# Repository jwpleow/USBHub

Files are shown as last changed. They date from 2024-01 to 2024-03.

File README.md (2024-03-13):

## Impedance Control
Impedance control was done assuming manufacturing using JLCPCB 6 layer PCB JLC06161H-7628
90Ohms Diff Pair (usb) -> 0.127mm spacing, 0.16mm trace width
100Ohms Diff Pair (ethernet) -> 0.127mm spacing, 0.11mm trace width

## Min vias
We require 0.15mm/0.25mm vias ($$$$$$$$$$$$)

### Red LED for PD fault
KT-0603R
https://jlcpcb.com/partdetail/Hubei_KentoElec-KT0603R/C2286

## Power
### 5V
| Part Name | Description | Datasheet | JLCPCB |
| - | - | - | - |
| TPS56637RPAR | 4.5-V to 24-V In, 0.6-V to 7-V Out, 8-A Synchronous Step-Down Voltage Regulator | [Datasheet](https://www.ti.com/lit/ds/symlink/tps51396a.pdf) | [JLCPCB](https://jlcpcb.com/partdetail/TexasInstruments-TPS56637RPAR/C841386) | 
| FXL0630-3R3-M | Inductor 3.3uH (max 22mOhm) 8.5A | | [JLCPCB](https://jlcpcb.com/partdetail/178602-FXL0630_3R3M/C167219) |

### 3V3
| Part Name | Description | Datasheet | JLCPCB |
| - | - | - | - |
| TLV75733PDBVR |  Fixed 3.3V 1A SOT-23-5 25uA qI | | [JLCPCB](https://jlcpcb.com/partdetail/TexasInstruments-TLV75733PDBVR/C485517) |

### 1V2
| Part Name | Description | Datasheet | JLCPCB |
| - | - | - | - |
| TPS54331DR | Step-down type Adjustable 0.8V~25V 3A 3.5V~28V Buck converter | [Datasheet](https://www.ti.com/lit/ds/symlink/tps54331.pdf) | [JLCPCB](https://jlcpcb.com/partdetail/TexasInstruments-TPS54331DR/C9865) |
| FNR6045S180MT | Inductor 18uH ±20% 2.4A SMD,6x6mm, 81mOhm |  | [JLCPCB](https://jlcpcb.com/partdetail/179462-FNR6045S180MT/C168079) |

## USB
### Power Delivery

| Part Name | Description | Datasheet | JLCPCB |
| - | - | - | - |
| CYPD3177_24LQXQ | USB Type-C and Power Delivery (PD) Controller QFN-24 | [Datasheet](https://www.infineon.com/dgdl/Infineon-EZ-PD_BCR_Datasheet_USB_Type-C_Port_Controller_for_Power_Sinks-DataSheet-v03_00-EN.pdf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) | [JLCPCB](https://jlcpcb.com/partdetail/CypressSemicon-CYPD317724LQXQ/C2959321) | 
| BZT52C12 | Zener Diode | | [JLCPCB](https://jlcpcb.com/partdetail/Goodwork-BZT52C12/C2932744) | 
| SI3421DV-T1-GE3 | PMOSFET | | [JLCPCB](https://jlcpcb.com/partdetail/VishayIntertech-SI3421DV_T1GE3/C144884) | 
| SS54 | Schottky Diode for Reverse Polarity Protection | | [JLCPCB](https://jlcpcb.com/partdetail/Hongjiacheng-SS54/C7420369) |

### USB Data

| Part Name | Description | Datasheet | JLCPCB |
| - | - | - | - |
| CYUSB3304-68LTXCT | USB 3.2 Gen1 4-port Hub Controller | [Datasheet](https://www.infineon.com/dgdl/Infineon-CYUSB330x_CYUSB331x_CYUSB332x_HX3_USB_3.0_Hub-DataSheet-v21_00-EN.pdf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) | [JLCPCB](https://jlcpcb.com/partdetail/CypressSemicon-CYUSB330468LTXCT/C914921) |
| TUSB522PPRGER | 5Gbps USB3.0 redriver | [Datasheet](https://www.ti.com/lit/ds/symlink/tusb522p.pdf) | [JLCPCB](https://jlcpcb.com/parts/componentSearch?searchTxt=TUSB522P)  |
| PI3USB302-AZBEX | USB 3.0 Passive mux | [Datasheet](https://www.diodes.com/assets/Datasheets/PI3USB302-A.pdf) |  [JLCPCB](https://jlcpcb.com/partdetail/DiodesIncorporated-PI3USB302AZBEX/C500787) |
| TXM26M0004322CBCDO00T | Crystal for USB Hub Controller 26MHz +- 10ppm 9pF | | [JLCPCB](https://jlcpcb.com/partdetail/Yajingxin-TXM26M0004322CBCDO00T/C362346) |
<!-- | TUSB212IRWBR | USB 2.0 Signal Conditioner | [Datasheet](https://www.ti.com/lit/ds/symlink/tusb212.pdf) | [JLCPCB](https://jlcpcb.com/partdetail/TexasInstruments-TUSB212IRWBR/C2674396) | -->

### USB Ancillaries
| Part Name | Description | Datasheet | JLCPCB |
| - | - | - | - |
| GT-USB-7052 | USB Type-C Receptacle USB3.1 5A 24 Pins Vertical SMD | [Datasheet](https://www.dg-switch.com/uploads/soft/200510/GT-USB-7052.pdf) | [JLCPCB](https://jlcpcb.com/partdetail/gswitch-GT_USB7052/C963223) |
| PUSB3FR4Z | ESD Protection for differential pairs | [Datasheet](https://assets.nexperia.com/documents/data-sheet/PUSB3FR4.pdf) | [JLCPCB](https://jlcpcb.com/partdetail/Nexperia-PUSB3FR4Z/C503418)  |
| TI TVS2200DRVR | ESD Protection 28V for VBUS | [Datasheet](https://www.ti.com/lit/ds/symlink/tvs2200.pdf) | [JLCPCB](https://jlcpcb.com/partdetail/TexasInstruments-TVS2200DRVR/C523793) |
| TPS2069CDBVR | 1.5A Current limiting power distribution switch for USB DFP | [Datasheet](https://www.ti.com/lit/ds/symlink/tps2001c.pdf) | [JLCPCB](https://jlcpcb.com/partdetail/TexasInstruments-TPS2069CDBVR/C181752) |
| ESD5B5.0ST1G | 5.8V ESD Protection for DFP VBUS | [Datasheet](https://www.onsemi.com/pdf/datasheet/esd5b5.0st1-d.pdf) | [JLCPCB](https://jlcpcb.com/partdetail/Onsemi-ESD5B50ST1G/C93623) | 
| 484080003 | USB Type A Vertical | | [JLCPCB](https://jlcpcb.com/partdetail/Molex-484080003/C587839) |

### Ethernet USB 
| Part Name | Description | Datasheet | JLCPCB |
| - | - | - | - |
| RTL8153B-VB-CG | Ethernet-USB controller |  | [JLCPCB](https://jlcpcb.com/partdetail/RealtekSemicon-RTL8153B_VBCG/C2802072)  |
| G24P02S | RJ45 Transformer | | [JLCPCB](https://jlcpcb.com/partdetail/Jasn-G24P02S/C2827276)  |
| 7D025000Q01 | 25MHz Crystal, 18pF +- 10ppm | | [JLCPCB](https://jlcpcb.com/partdetail/Hd-7D025000Q01/C648942)|
| RC01931 | Ethernet Port Vertical | | [JLCPCB](https://jlcpcb.com/partdetail/Rch-RC01931/C708651) |

### Others
| Part Name | Description | Datasheet | JLCPCB |
| - | - | - | - |
| KT-0805G | LED Green | | [JLCPCB](https://jlcpcb.com/partdetail/Hubei_KentoElec-KT0805G/C2297) |
| BLM21PG221SN1D | Ferrite Bead 2A @ 85C | | [JLCPCB](https://jlcpcb.com/partdetail/MurataElectronics-BLM21PG221SN1D/C85840) |
| WJ103-5.0-2P | 2P 5mm screw terminal angled | | [JLCPCB](https://jlcpcb.com/partdetail/Ningbo_KangnexElec-WJ103_5_02P/C8439 )  |
| RVT1V151M0607 | 150u Aluminium Electrolytic Capacitor | | [JLCPCB](https://jlcpcb.com/partdetail/Roqang-RVT1V151M0607/C3032176) |
 <!-- | TI TPDxE05U06 | ESD Protection TVS 28V for CC / DP / DM?  | [Datasheet](https://www.ti.com/lit/ds/symlink/tpd4e05u06.pdf) | [JLCPCB](https://jlcpcb.com/partdetail/TexasInstruments-TPD4E05U06DQAR/C138714)  -->

## Buck Converter to 5V

## USB Hub Design Checklist
1 Are the decoupling capacitors and bulk capacitors connected as per Figure 1 and Figure 2? Y
2 Does the crystal meet the specification in this application note?  Y
3 Are all DS ports provided with 150-µF bulk capacitors? Y
4 Do the Power-on-Reset RC components meet the minimum reset time (5 ms)? Y
5 Do the USB precision resistors have 1% tolerance?  Y
6 Are the I2C lines provided with pull-up resistors to the 3.3-V domain? Y
7 Do the LEDs connected to the pin-strap pins have a 10-kΩ parallel resistor? Y
8
Is it ensured that the DS port power switch has a MOSFET connected to the OUTPUT pin or selected a power switch with
fast discharge? Y
9 Is the VBUS_US pin provided with a 10-kΩ voltage divider network? Y
10 Is the US port provided with 1-µF bulk capacitor? N
11 Are all port shields terminated properly?
12 Are the ferrite beads connected as shown in Figure 1 and Figure 2?
13
Are MODE_SEL[1] and MODE_SEL[0] not pulled LOW when the pin-strap configuration is used with HX3? (For 88-pin
QFN only).
14
Are values of the resistors connected in series to the LEDs decided based on the HX3’s I/O current source/sink capability
(4 mA)?
Layout Checklist
1 Is the crystal placed close to the chip (less than 1 cm)?
2 Are the decoupling capacitors and bulk capacitors placed close to the HX3 power pins?
3 Are the vias placed close to the HX3 power pins?
4 Are the power traces routed away from the high-speed data lines and the clock lines?
5 Is the capacitor in the RC reset circuitry placed close to the reset pin of HX3?
6 Is the 150-µF capacitor placed close to the DS port connector?
7 Are the USB SS and HS signal lines matched in length?
8 Are the USB data lines provided with solid ground plane underneath?
9 Are the SS traces provided with the guard traces along the USB data trace with stitching vias?
10 Are the SS traces provided with the AC decoupling capacitors (0.1 µF) on the TX lines?
11 Are the USB traces kept as short as possible?
12 Is it ensured that there are no stubs on all the USB traces?
13 Is it ensured that there are no vias on the SS traces?
14 Do the USB traces have few bends and no 90-degree bends?

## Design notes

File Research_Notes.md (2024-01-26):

# Notes
https://www.youtube.com/watch?v=W13HNsoHj7A USB-C Power Delivery Hardware Design - Phil's Lab #104
https://www.ti.com/lit/wp/slyy109b/slyy109b.pdf?ts=1704425741746 A Primer on USB Type-C and USBPower Delivery Applications and Requirements

# USB 3 hub examples
https://github.com/DynamixYANG/highendusb3hub
https://www.ti.com/lit/ug/slla312c/slla312c.pdf

# USB PD examples
https://www.ti.com/lit/ug/slvubo9a/slvubo9a.pdf

# Parts check: 
https://www.pcbway.com/components/
https://jlcpcb.com/parts/

## Find Symbols + Footprints
https://componentsearchengine.com/
https://easyeda.com/

# STM32
STM32F103C8T6 https://jlcpcb.com/partdetail/Stmicroelectronics-STM32F103C8T6/C8734

QFN package - more complicated :0?
3.3V <- Needs a regulator from USB, ~100mA?
USB natively on board!
CAN timers 

# DC converter
harder to route than an LDO regulator

How to choose switching regulator:
SMD type 
Skip BGA (expensive to assemble)

Pick simple `Buck` in Topology..
Pick correct output voltage & output current

### Recommendations by https://www.youtube.com/watch?v=_4h2ZD8O9Ms
1. TUSB422 + TPS65987D + TUSB542 + TUSB212 (5Gbps)
2. TUSB422 + TPS65987D + TUSB1042I + TUSB212 (10Gbps)

TPS65987D -> Power delivery
TUSB212 -> USB 2 controller

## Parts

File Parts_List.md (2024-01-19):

# Power

### Power delivery controller - CYPD3177-24LQXQ
https://au.mouser.com/datasheet/2/196/CYPR_S_A0012903526_1-3004964.pdf
https://jlcpcb.com/partdetail/CypressSemicon-CYPD317724LQXQ/C2959321

### MOSFET for PD controller 
#### SI3421DV-T1-GE3
https://jlcpcb.com/partdetail/VishayIntertech-SI3421DV_T1GE3/C144884

### Zener Diode for PD controller
https://jlcpcb.com/partdetail/Goodwork-BZT52C12/C2932744

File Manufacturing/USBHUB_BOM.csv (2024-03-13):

Designator | Qnty | Comment | Cmp name | Footprint | Description | JLCPCB Part #
C1, C115, C119, C123 | 4 | 150u | C_Small | Capacitor_SMD:C_Elec_6.3x7.7 | Unpolarized capacitor, small symbol | C3032176
C2, C3, C5, C7, C18, C19, C53, C57, C73, C87, C100, C106, C130, C132 | 14 | 1u | C_Small | 0603 | Unpolarized capacitor, small symbol | C15849
C4 | 1 | 3u3 | C_Small | 0603 | Unpolarized capacitor, small symbol | C5360803
C6, C8, C9, C20, C22, C114, C116, C117, C118, C120, C121, C122, C124, C125 | 14 | 100n | C_Small | 0603 | Unpolarized capacitor, small symbol | C30926
C10, C11, C52, C72, C86, C99, C105, C113 | 8 | 22u | C | 0603 | Unpolarized capacitor | C59461
C12, C13, C131, C133, C134 | 5 | 4u7 | C_Small | 0603 | Unpolarized capacitor, small symbol | C19666
C14, C16 | 2 | 10n | C_Small | 0603 | Unpolarized capacitor, small symbol | C57112
C15 | 1 | 3n9 | C_Small | 0603 | Unpolarized capacitor, small symbol | C2169349
C17 | 1 | 18n | C_Small | 0603 | Unpolarized capacitor, small symbol | C519551
C21, C23, C24 | 3 | 22u | C | 0805 | Unpolarized capacitor | C45783
C25 | 1 | 100p | C | 0603 | Unpolarized capacitor | C14858
C26, C27, C28, C29, C58, C60, C62, C64, C66, C68, C75, C77, C79, C81, C89, C91, C93, C95, C97, C102, C104, C108, C110, C112, C147, C148, C149, C151, C152 | 29 | 10n | C_Small | 0402 | Unpolarized capacitor, small symbol | C15195
C30, C31 | 2 | 220pF | C_Small | 0402 | Unpolarized capacitor, small symbol | C1530
C32, C35, C38, C39, C40, C128 | 6 | 10u | C_Small | 0603 | Unpolarized capacitor, small symbol | C19702
C33, C34, C36, C37, C41, C42, C43, C44, C45, C46, C47, C48, C49, C54, C55, C56, C59, C70, C71, C74, C76, C78, C80, C82, C83, C84, C85, C88, C101, C103, C107, C109, C111, C129, C135, C136, C137, C138, C139, C140, C141, C142, C143, C144, C145, C146, C153 | 47 | 100n | C_Small | 0402 | Unpolari capacitor, small symbol | C1525
C50, C51 | 2 | 10p | C | 0402 | Unpolarized capacitor | C32949
C61, C63, C65, C67, C69, C90, C92, C94, C96, C98 | 10 | 1n | C_Small | 0402 | Unpolarized capacitor, small symbol | C1523
C126, C127 | 2 | 27p | C | 0402 | Unpolarized capacitor | C1557
C150 | 1 | 1n/2KV | C | 1206 | Unpolarized capacitor | C9196
D1 | 1 | BZT52C12 | D_Zener | Diode_SMD:D_SOD-123 | Zener diode | C2932744
D2, D14 | 2 | RED | LED | 0603 | Light emitting diode | C2286
D3, D18 | 1 | SS54 | D_Schottky | Diode_SMD:D_SMA | 40V 5A Schottky Barrier Rectifier Diode, SMA | C7420369
D4 | 1 | GREEN | LED | 0603 | Light emitting diode | C2297
D5, D6, D7, D8, D9, D10, D11, D12, D13 | 9 | PUSB3FR4Z | PUSB3FR4Z | PUSB3FR4Z |  | C503418
D15, D16, D17 | 3 | ESD5B5.0ST1G | D_Zener | Diode_SMD:D_SOD-523 | Zener diode | C93623
FB1, FB2 | 2 | BLM21PG221SN1D | FerriteBead_Small | 0805 | Ferrite bead, small symbol | C85840
J1 | 1 | USB_C_Receptacle | USB_C_Receptacle | USB_C_Receptacle_GT-USB-7028x |  | C963223
J2 | 1 | RC01931 | RC01931 | RC01931 | Ethernet RJ45, Vertical | C708651
J3 | 1 | Screw_Terminal_01x02 | Screw_Terminal_01x02 | TerminalBlock_WJ103-5.0-2P | Generic screw terminal, single row, 01x02, script genera (kicad-library-utils/schlib/autogen/connector/) | C8439
L1 | 1 | 18u | L | FNR6045Sx | Inductor | C168079
L2 | 1 | 3.3u | L | FXL0630x | Inductor | C167219
Q1, Q2 | 2 | SI3421DV | SI3421DV | Package_TO_SOT_SMD:SOT-23-6 | P-MOSFET transistor, gate/source/drain | C144884
R1 | 1 | 10k | R | 0603 | Resistor | C25804
R2 | 1 | 50k | R | 0603 | Resistor | C304067
R3, R5, R6, R7, R13, R15, R16, R18, R19, R21, R30, R31, R32, R33, R34, R38, R39, R40, R41, R43 | 20 | 10k | R_Small | 0402 | Resistor | C25744
R4, R24, R25, R26, R27, R48, R49 | 7 | 1k | R | 0603 | Resistor | C25744
R8, R9, R35, R36 | 4 | 2k | R | 0402 | Resistor | C4109
R10, R11, R12, R22, R23, R37 | 6 | 5k1 | R | 0603 | Resistor | C23186
R14 | 1 | 953 | R | 0603 | Resistor | C311896
R17 | 1 | 100k | R | 0603 | Resistor | C25803
R20 | 1 | 73k2 | R | 0402 | Resistor | C185398
R28 | 1 | 200_1% | R | 0402 | Resistor | C25087
R29 | 1 | 6k04_1% | R | 0402 | Resistor | C25913
R42 | 1 | 2k49_1% | R_Small | 0603 | Resistor | C22908
R44, R45, R46, R47 | 4 | 75 | R_Small | 0603 | Resistor | C4275
R50, R51 | 2 | 10k | R_Small | 0402 | Resistor | C25744
T1 | 1 | G24P02S | G24P02S | G24P02S | RJ45 100/1000 Base-T SMT Transformer | C2827276
U1 | 1 | CYPD3177_24x | CYPD3177_24x | CYPD3177_24LQx_QFN-24_EP_4x4_Pitch0.5mm | USB Type-C PD Port Controller for Power Sinks | C2959321
U2 | 1 | TPS54331 | TPS54331DR | TPS54331DR | 3.5 to 28-V Input, 3A Step Down Buck Converter 570kHz | C9865
U3 | 1 | TLV75733PDBV | TLV75733PDBV | Package_TO_SOT_SMD:SOT-23-5 | 1A Low IQ Small Size Low Dropout Voltage Regulator, Fixed Output 3. SOT-23-5 | C485517
U4 | 1 | TPS56637RPAR | TPS56637RPAR | TPS56637RPAR |  | C841386
U5 | 1 | TVS2200DRVx | TVS2200DRVx | TVS2200DRVx |  | C523793
U6 | 1 | PI3USB302-Ax | PI3USB302-Ax | PI3USB302-Ax | 3.3V, USB 3.0, 1-Port, 2:1 Mux/DeMux Switch | C500787
U7 | 1 | TUSB522Px | TUSB522Px | TUSB522Px | 3.3 V Dual-Channel USB 3.1 GEN 1 Redriver, Equalizer | C2675181
U8, U9, U10 | 3 | USB_3_Type_A_Molex_484080003 | USB_3_Type_A_Molex_484080003 | Molex_484080003 |  | C587839
U11 | 1 | CYUSB3304-68LTXx | CYUSB3304-68LTXx | CYUSB3304-68LTXx |  | C914921
U12, U13, U14 | 3 | TPS20xxC | TPS20xxC | Package_TO_SOT_SMD:SOT-23-5 |  | C181752
U15 | 1 | RTL8153-VB-CG | RTL8153B-VB-CG | RTL8153B-VB-CG |  | C2802072
Y1 | 1 | 26MHz | Crystal_GND24 | Crystal:Crystal_SMD_3225-4Pin_3.2x2.5mm | Four pin crystal, GND on pins 2 and 4 | C362346
Y2 | 1 | 25MHz 18pF | Crystal_GND24 | Crystal:Crystal_SMD_2016-4Pin_2.0x1.6mm | Four pin crystal, GND on pins 2 and 4 | C648942

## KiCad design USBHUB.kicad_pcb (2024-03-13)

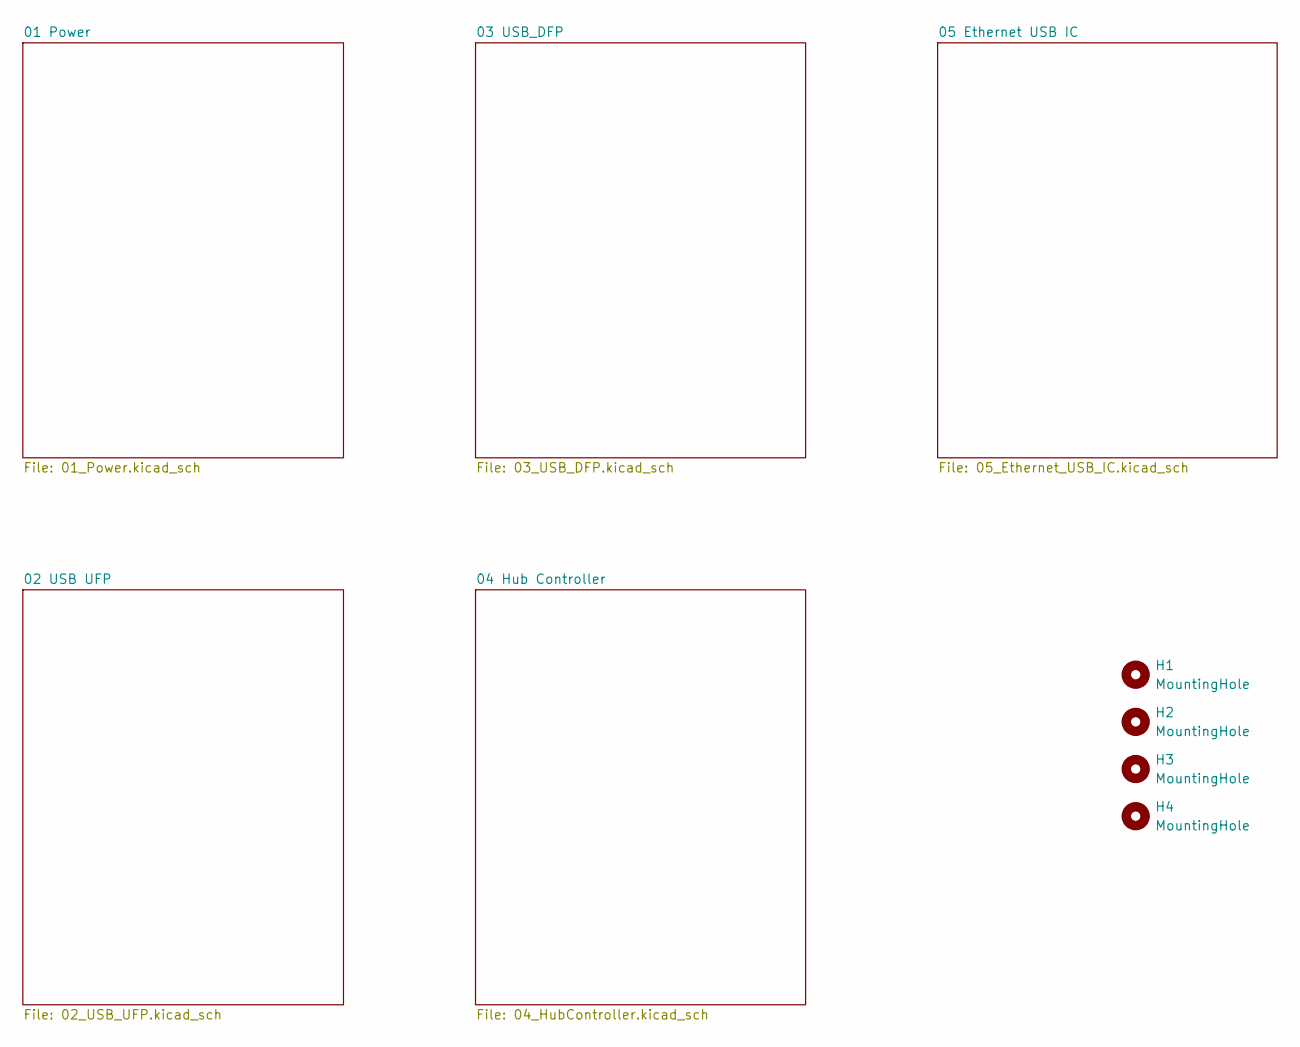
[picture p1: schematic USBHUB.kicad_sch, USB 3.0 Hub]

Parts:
H1, H2, H3, H4: MountingHole; MountingHole_2.7mm_M2.5

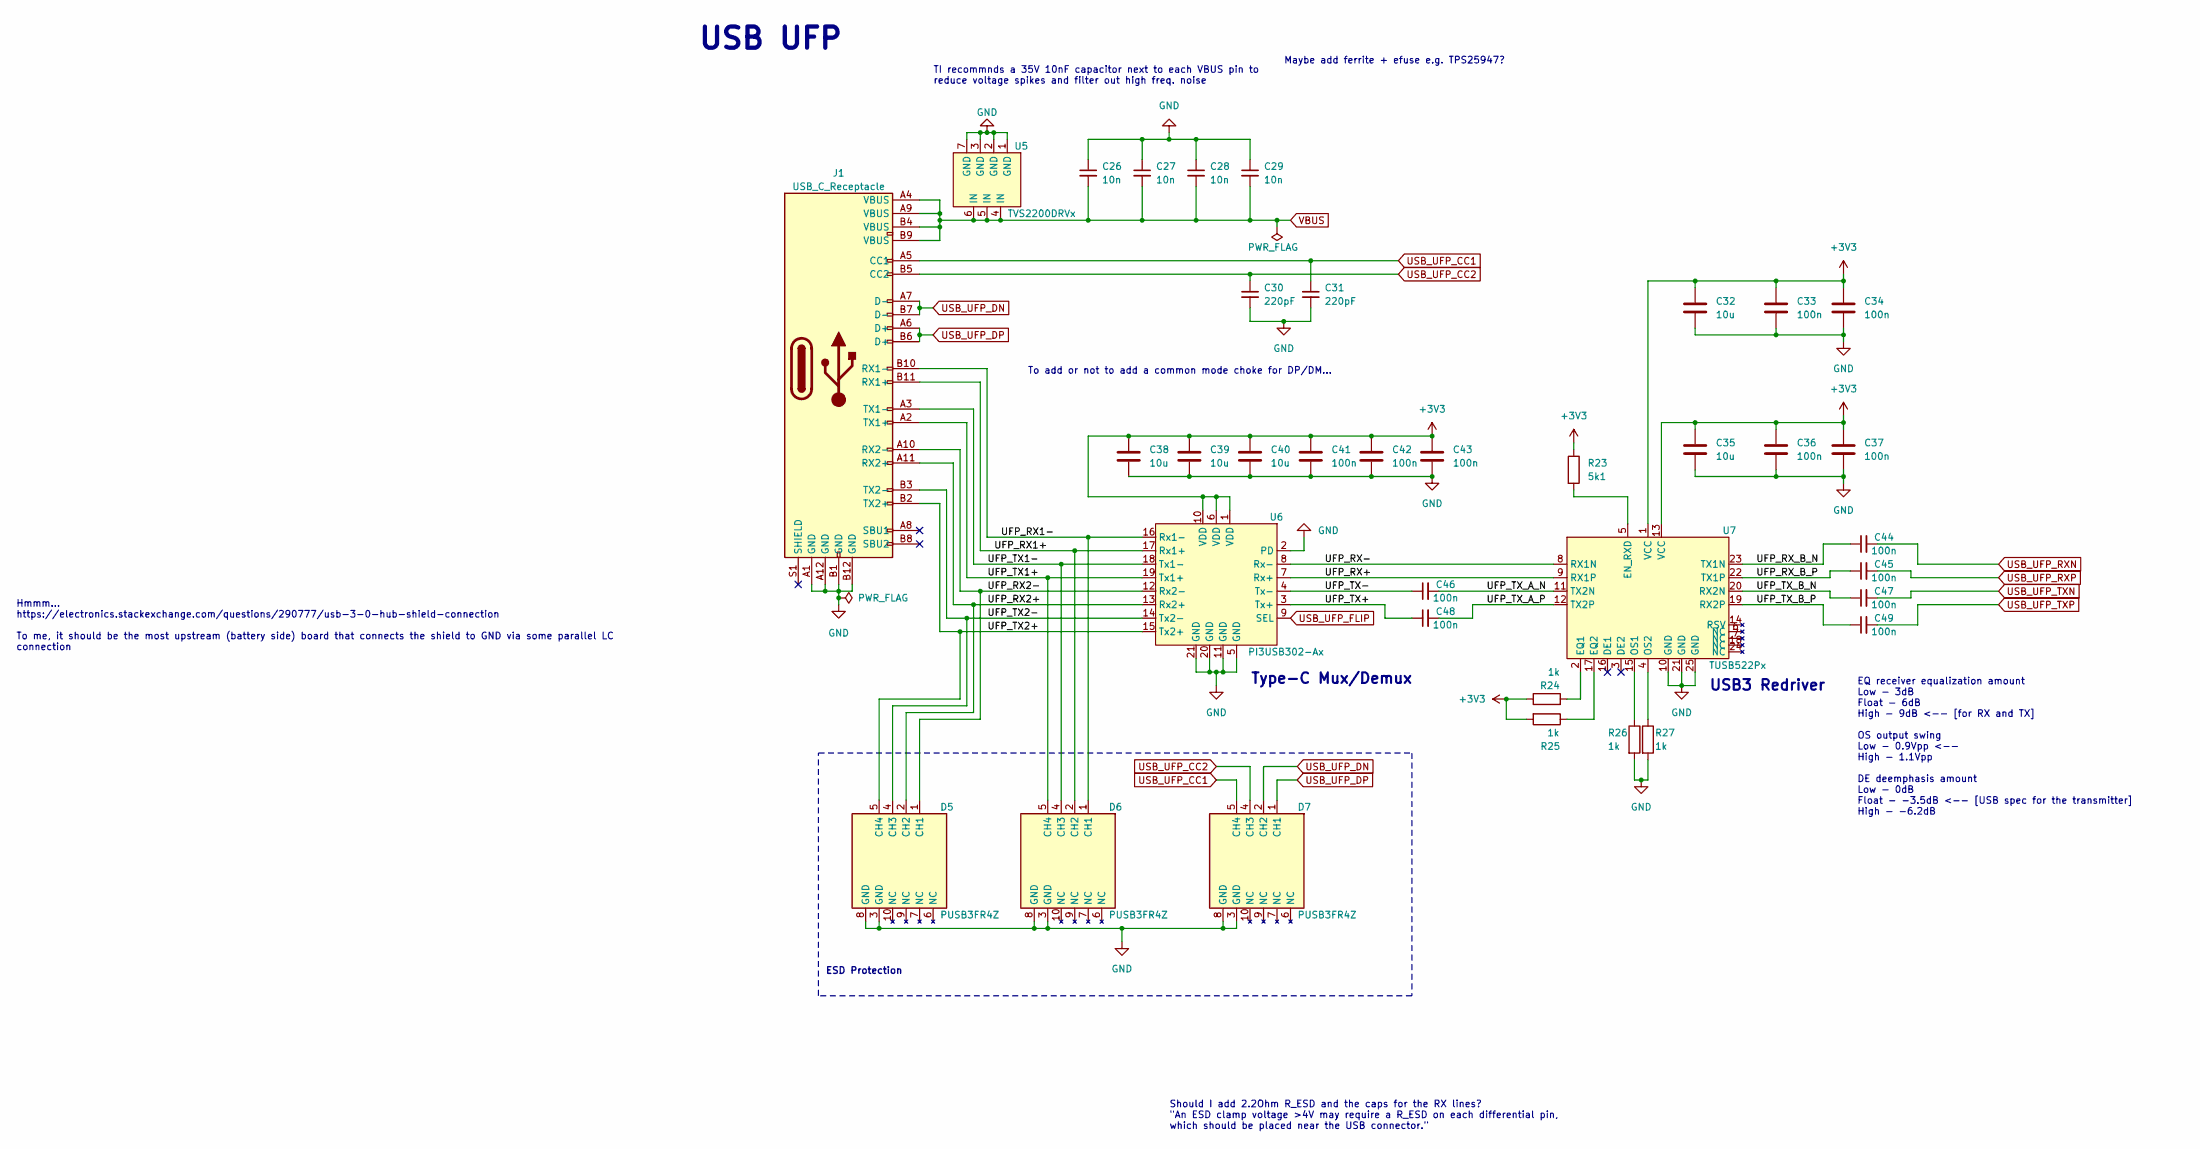
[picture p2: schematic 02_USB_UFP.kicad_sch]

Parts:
C26, C27, C28, C29: 10n; C_0402_1005Metric
C30, C31: 220pF; C_0402_1005Metric
C32, C35, C38, C39, C40: 10u; C_0603_1608Metric
C33, C34, C36, C37, C41, C42, C43, C44, C45, C46, C47, C48, C49: 100n; C_0402_1005Metric
D5, D6, D7: PUSB3FR4Z
J1: USB_C_Receptacle; USB_C_Receptacle_GT-USB-7028x
R23: 5k1; R_0603_1608Metric
R24, R25, R26, R27: 1k; R_0603_1608Metric
U5: TVS2200DRVx
U6: PI3USB302-Ax
U7: TUSB522Px

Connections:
+3V3: C32.1, C33.1, C34.1, C35.1, C36.1, C37.1, C38.1, C39.1, C40.1, C41.1, C42.1, C43.1, R23.1, R24.1, R25.2, U6.1 (VDD), U6.6 (VDD), U6.10 (VDD), U7.1 (VCC), U7.13 (VCC); also elsewhere on the board
/02 USB UFP/UFP_RX1+: D6.2 (CH2), J1.B11 (RX1+), U6.17 (Rx1+)
/02 USB UFP/UFP_RX1-: D6.1 (CH1), J1.B10 (RX1-), U6.16 (Rx1-)
/02 USB UFP/UFP_RX2+: D5.2 (CH2), J1.A11 (RX2+), U6.13 (Rx2+)
/02 USB UFP/UFP_RX2-: D5.1 (CH1), J1.A10 (RX2-), U6.12 (Rx2-)
/02 USB UFP/UFP_RX+: U6.7 (Rx+), U7.9 (RX1P)
/02 USB UFP/UFP_RX-: U6.8 (Rx-), U7.8 (RX1N)
/02 USB UFP/UFP_RX_B_N: C44.1, U7.23 (TX1N)
/02 USB UFP/UFP_RX_B_P: C45.1, U7.22 (TX1P)
/02 USB UFP/UFP_TX1+: D6.5 (CH4), J1.A2 (TX1+), U6.19 (Tx1+)
/02 USB UFP/UFP_TX1-: D6.4 (CH3), J1.A3 (TX1-), U6.18 (Tx1-)
/02 USB UFP/UFP_TX2+: D5.5 (CH4), J1.B2 (TX2+), U6.15 (Tx2+)
/02 USB UFP/UFP_TX2-: D5.4 (CH3), J1.B3 (TX2-), U6.14 (Tx2-)
/02 USB UFP/UFP_TX+: C48.1, U6.3 (Tx+)
/02 USB UFP/UFP_TX-: C46.1, U6.4 (Tx-)
/02 USB UFP/UFP_TX_A_N: C46.2, U7.11 (TX2N)
/02 USB UFP/UFP_TX_A_P: C48.2, U7.12 (TX2P)
/02 USB UFP/UFP_TX_B_N: C47.1, U7.20 (RX2N)
/02 USB UFP/UFP_TX_B_P: C49.1, U7.19 (RX2P)
GND: C26.1, C27.1, C28.1, C29.1, C30.2, C31.2, C32.2, C33.2, C34.2, C35.2, C36.2, C37.2, C38.2, C39.2, C40.2, C41.2, C42.2, C43.2, D5.3 (GND), D5.8 (GND), D6.3 (GND), D6.8 (GND), D7.3 (GND), D7.8 (GND), J1.A1 (GND), J1.A12 (GND), J1.B1 (GND), J1.B12 (GND), R26.2, R27.2, U5.1 (GND), U5.2 (GND), U5.3 (GND), U5.7 (GND), U6.2 (PD), U6.5 (GND), U6.11 (GND), U6.20 (GND), U6.21 (GND), U7.10 (GND), U7.21 (GND), U7.25 (GND); also elsewhere on the board
unnamed: R23.2, U7.5 (EN_RXD)
unnamed: R24.2, U7.2 (EQ1)
unnamed: R25.1, U7.17 (EQ2)
unnamed: R26.1, U7.15 (OS1)
unnamed: R27.1, U7.4 (OS2)
USB_UFP_CC1: C31.1, D7.5 (CH4), J1.A5 (CC1); also elsewhere on the board
USB_UFP_CC2: C30.1, D7.4 (CH3), J1.B5 (CC2); also elsewhere on the board
USB_UFP_DN: D7.2 (CH2), J1.A7 (D-), J1.B7 (D-); also elsewhere on the board
USB_UFP_DP: D7.1 (CH1), J1.A6 (D+), J1.B6 (D+); also elsewhere on the board
USB_UFP_FLIP: U6.9 (SEL); also elsewhere on the board
USB_UFP_RXN: C44.2; also elsewhere on the board
USB_UFP_RXP: C45.2; also elsewhere on the board
USB_UFP_TXN: C47.2; also elsewhere on the board
USB_UFP_TXP: C49.2; also elsewhere on the board
VBUS: C26.2, C27.2, C28.2, C29.2, J1.A4 (VBUS), J1.A9 (VBUS), J1.B4 (VBUS), J1.B9 (VBUS), U5.4 (IN), U5.5 (IN), U5.6 (IN); also elsewhere on the board

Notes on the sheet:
TI recommnds a 35V 10nF capacitor next to each VBUS pin to reduce voltage spikes and filter out high freq. noise
Maybe add ferrite + efuse e.g. TPS25947?
Type-C Mux/Demux
ESD Protection
To add or not to add a common mode choke for DP/DM...
EQ receiver equalization amount Low - 3dB Float - 6dB High - 9dB <-- [for RX and TX] OS output swing Low - 0.9Vpp <-- High - 1.1Vpp DE deemphasis amount Low - 0dB Float - -3.5dB <-- [USB spec for the transmitter] High - -6.2dB
USB3 Redriver
Hmmm... https://electronics.stackexchange.com/questions/290777/usb-3-0-hub-shield-connection To me, it should be the most upstream (battery side) board that connects the shield to GND via some parallel LC connection
Should I add 2.2Ohm R_ESD and the caps for the RX lines? "An ESD clamp voltage >4V may require a R_ESD on each differential pin, which should be placed near the USB connector."
USB UFP

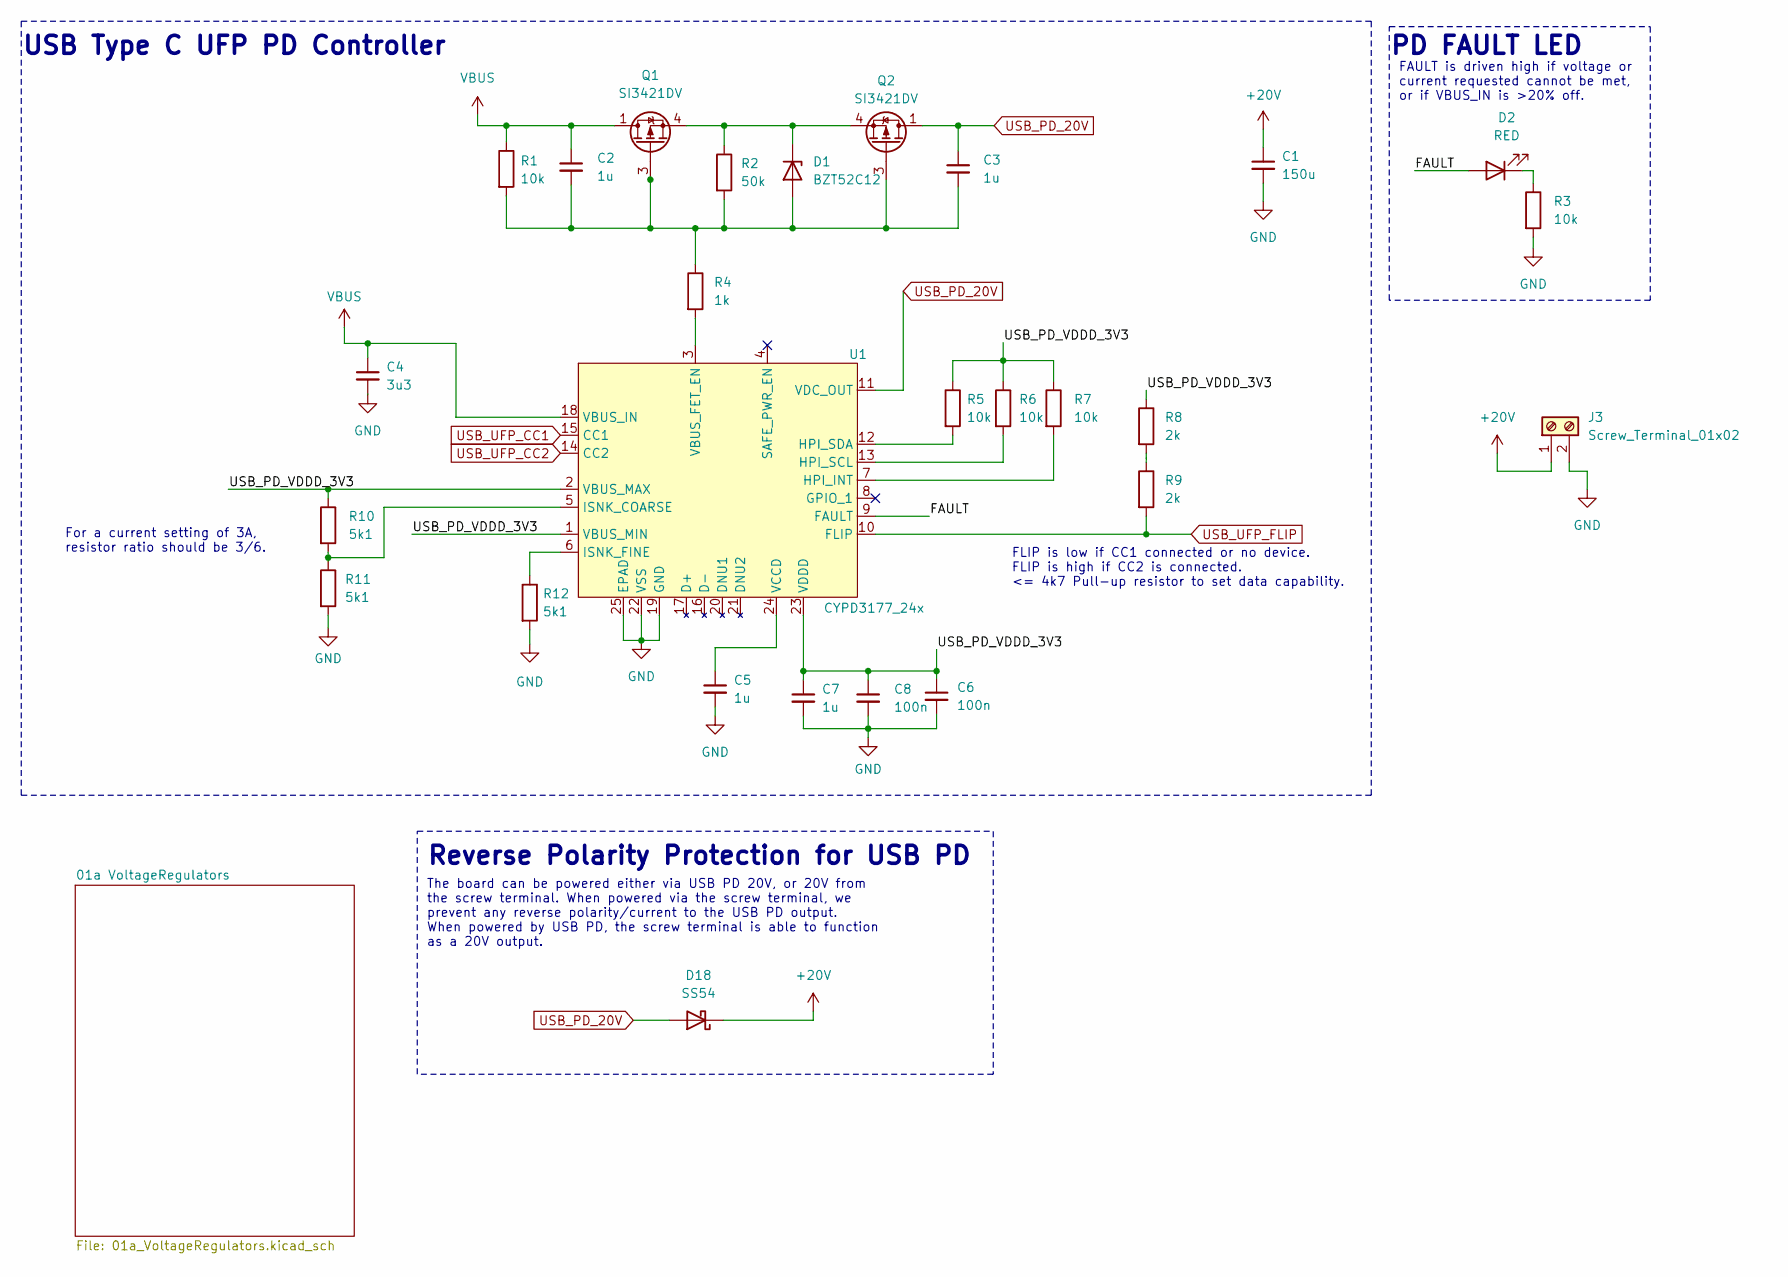
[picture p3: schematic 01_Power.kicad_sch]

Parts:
C1: 150u; C_Elec_6.3x7.7
C2, C3, C5, C7: 1u; C_0603_1608Metric
C4: 3u3; C_0603_1608Metric
C6, C8: 100n; C_0603_1608Metric
D1: BZT52C12; D_SOD-123
D2: RED; LED_0603_1608Metric
D18: SS54; D_SMA
J3: Screw_Terminal_01x02; TerminalBlock_WJ103-5.0-2P
Q1, Q2: SI3421DV; SOT-23-6
R1: 10k; R_0603_1608Metric
R2: 50k; R_0603_1608Metric
R3, R5, R6, R7: 10k; R_0402_1005Metric
R4: 1k; R_0603_1608Metric
R8, R9: 2k; R_0402_1005Metric
R10, R11, R12: 5k1; R_0603_1608Metric
U1: CYPD3177_24x; CYPD3177_24LQx_QFN-24_EP_4x4_Pitch0.5mm

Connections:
+20V: C1.1, D18.1 (K), J3.1; also elsewhere on the board
/01 Power/FAULT: D2.2 (A), U1.9 (FAULT)
/01 Power/USB_PD_VDDD_3V3: C6.1, C7.1, C8.1, R5.1, R6.1, R7.1, R8.1, R10.1, U1.1 (VBUS_MIN), U1.2 (VBUS_MAX), U1.23 (VDDD)
GND: C1.2, C4.2, C5.2, C6.2, C7.2, C8.2, J3.2, R3.2, R11.2, R12.2, U1.19 (GND), U1.22 (VSS), U1.25 (EPAD); also elsewhere on the board
unnamed: C2.2, C3.2, D1.2 (A), Q1.3 (G), Q2.3 (G), R1.2, R2.2, R4.1
unnamed: D1.1 (K), Q1.4 (S), Q2.4 (S), R2.1
unnamed: D2.1 (K), R3.1
unnamed: R8.2, R9.1
unnamed: R7.2, U1.7 (HPI_INT)
unnamed: R6.2, U1.13 (HPI_SCL)
unnamed: R5.2, U1.12 (HPI_SDA)
unnamed: R10.2, R11.1, U1.5 (ISNK_COARSE)
unnamed: R12.1, U1.6 (ISNK_FINE)
unnamed: R4.2, U1.3 (VBUS_FET_EN)
unnamed: C5.1, U1.24 (VCCD)
USB_PD_20V: C3.1, D18.2 (A), Q2.1 (D), Q2.2 (D1), Q2.5 (D2), Q2.6 (D3), U1.11 (VDC_OUT)
USB_UFP_CC1: U1.15 (CC1); also elsewhere on the board
USB_UFP_CC2: U1.14 (CC2); also elsewhere on the board
USB_UFP_FLIP: R9.2, U1.10 (FLIP); also elsewhere on the board
VBUS: C2.1, C4.1, Q1.1 (D), Q1.2 (D1), Q1.5 (D2), Q1.6 (D3), R1.1, U1.18 (VBUS_IN); also elsewhere on the board

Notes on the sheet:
For a current setting of 3A, resistor ratio should be 3/6.
FLIP is low if CC1 connected or no device. FLIP is high if CC2 is connected. <= 4k7 Pull-up resistor to set data capability.
USB Type C UFP PD Controller
PD FAULT LED
The board can be powered either via USB PD 20V, or 20V from the screw terminal. When powered via the screw terminal, we prevent any reverse polarity/current to the USB PD output. When powered by USB PD, the screw terminal is able to function as a 20V output.
Reverse Polarity Protection for USB PD
FAULT is driven high if voltage or current requested cannot be met, or if VBUS_IN is >20% off.

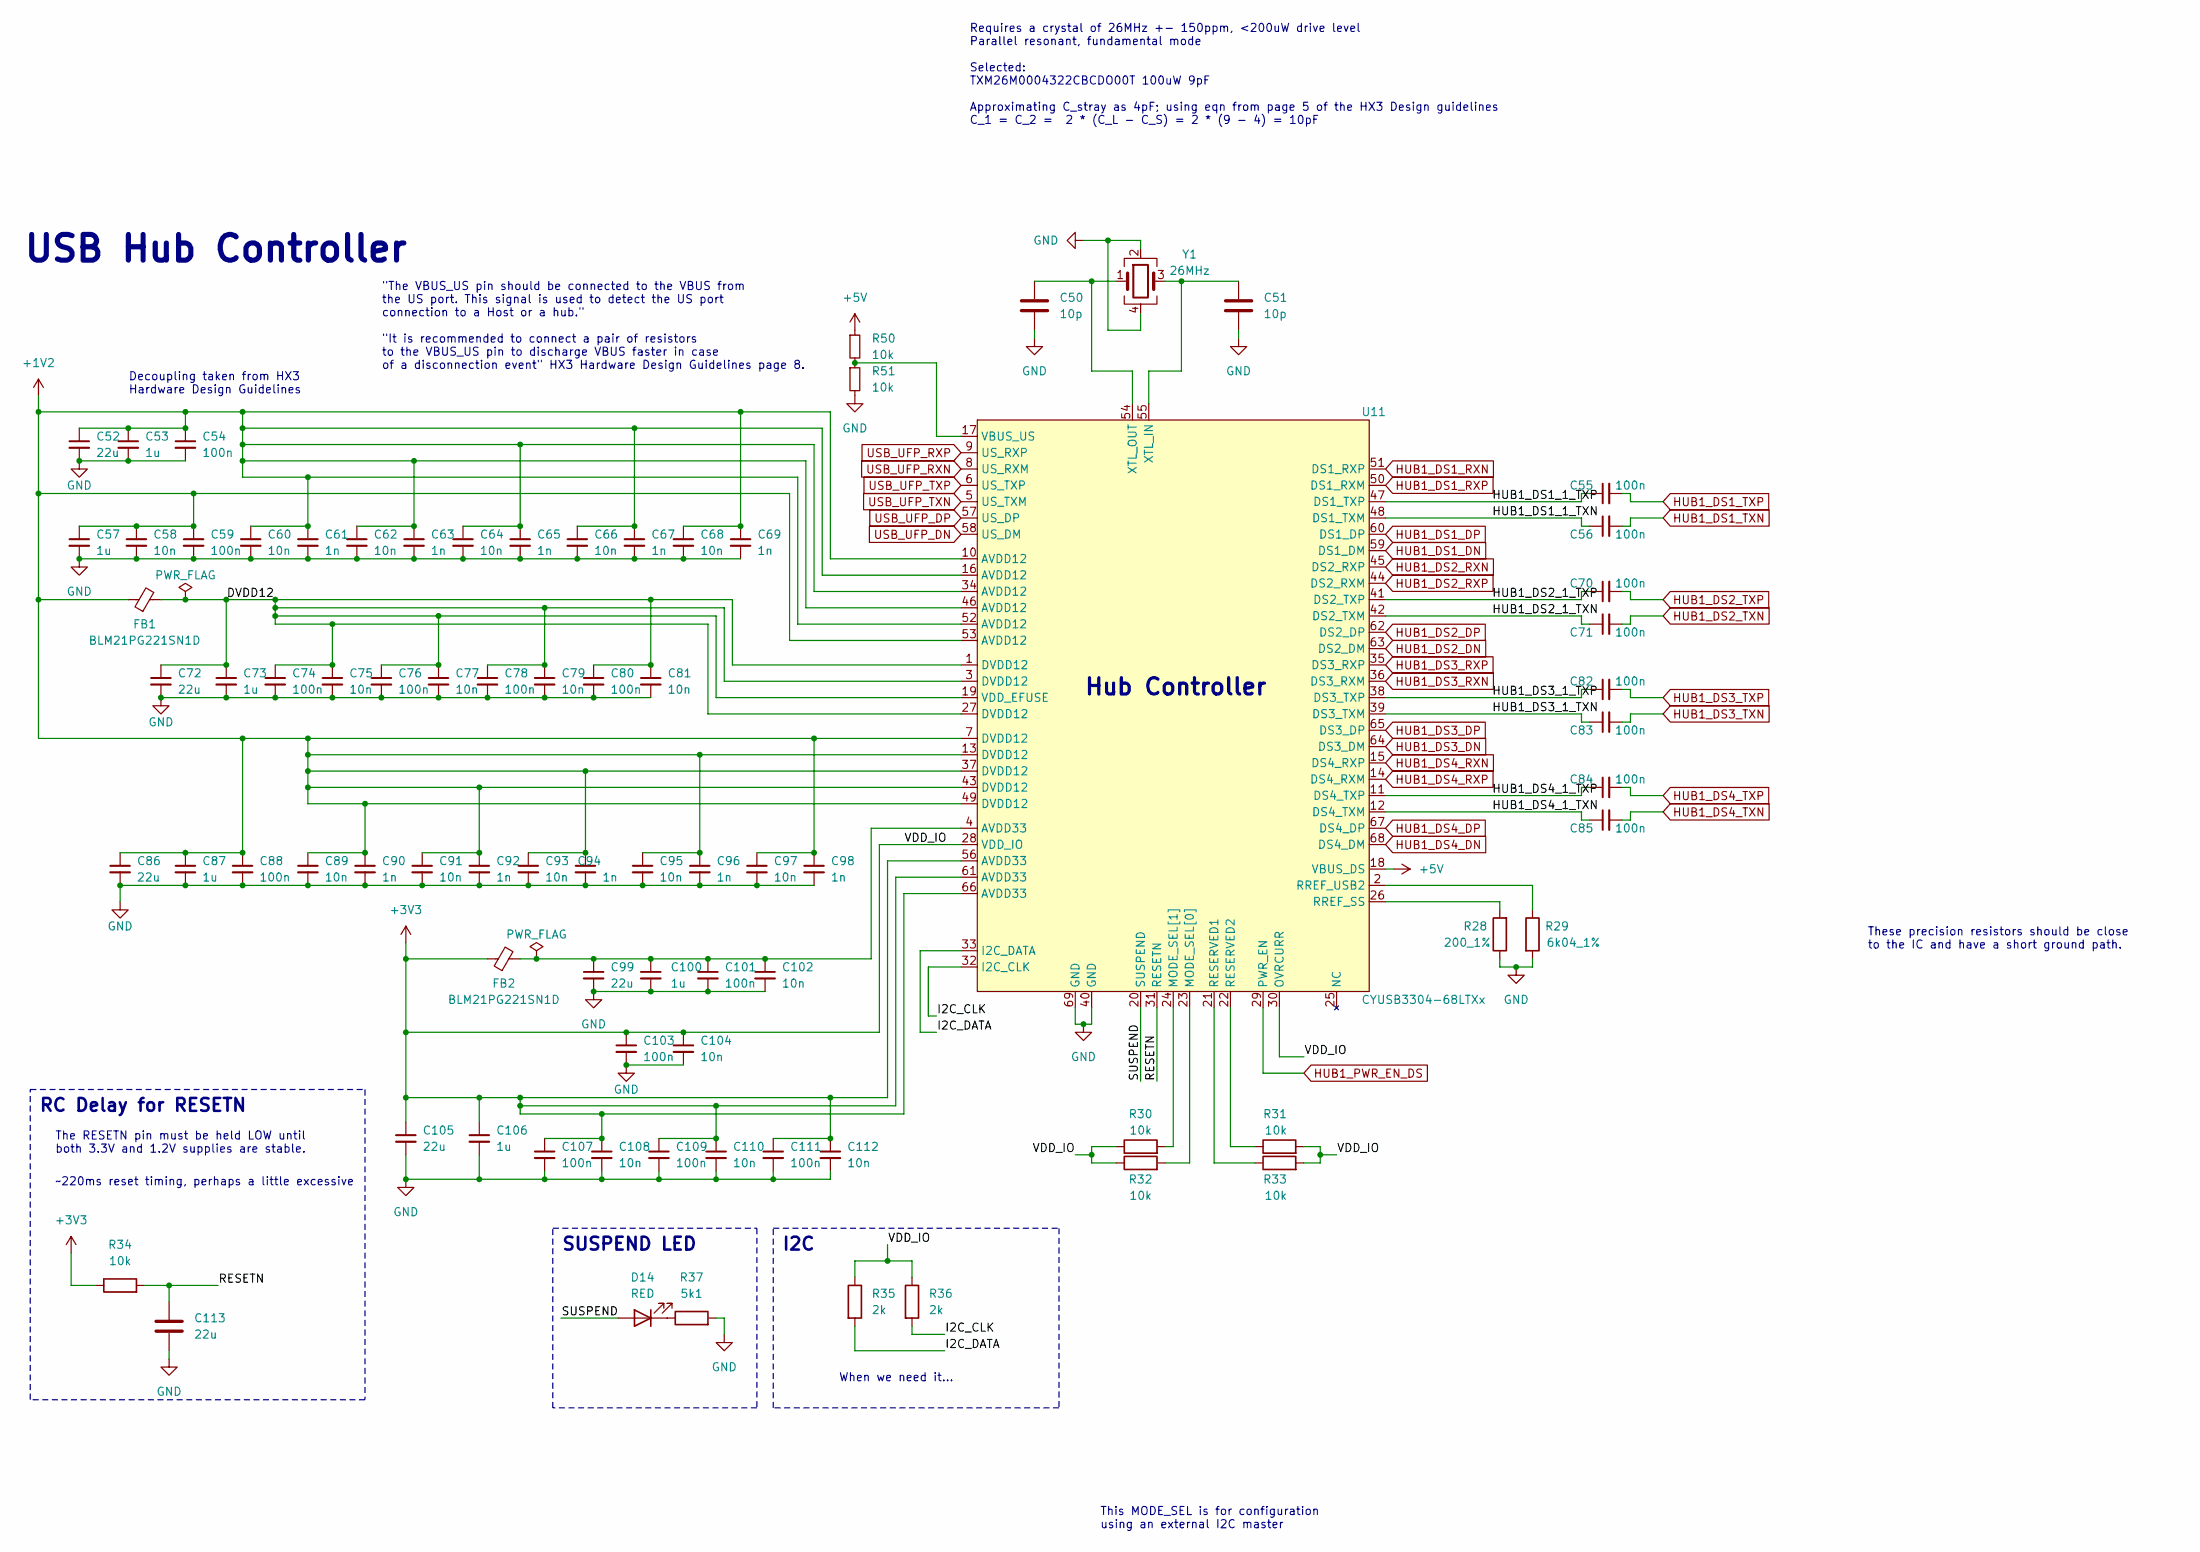
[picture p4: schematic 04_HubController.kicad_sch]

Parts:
C50, C51: 10p; C_0402_1005Metric
C52, C72, C86, C99, C105, C113: 22u; C_0603_1608Metric
C53, C57, C73, C87, C100, C106: 1u; C_0603_1608Metric
C54, C55, C56, C59, C70, C71, C74, C76, C78, C80, C82, C83, C84, C85, C88, C101, C103, C107, C109, C111: 100n; C_0402_1005Metric
C58, C60, C62, C64, C66, C68, C75, C77, C79, C81, C89, C91, C93, C95, C97, C102, C104, C108, C110, C112: 10n; C_0402_1005Metric
C61, C63, C65, C67, C69, C90, C92, C94, C96, C98: 1n; C_0402_1005Metric
D14: RED; LED_0603_1608Metric
FB1, FB2: BLM21PG221SN1D; L_0805_2012Metric
R28: 200_1%; R_0402_1005Metric
R29: 6k04_1%; R_0402_1005Metric
R30, R31, R32, R33, R34, R50, R51: 10k; R_0402_1005Metric
R35, R36: 2k; R_0402_1005Metric
R37: 5k1; R_0603_1608Metric
U11: CYUSB3304-68LTXx
Y1: 26MHz; Crystal_SMD_3225-4Pin_3.2x2.5mm

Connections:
+1V2: C52.1, C53.1, C54.1, C57.1, C58.1, C59.1, C60.1, C61.1, C62.1, C63.1, C64.1, C65.1, C66.1, C67.1, C68.1, C69.1, C86.1, C87.1, C88.1, C89.1, C90.1, C91.1, C92.1, C93.1, C94.1, C95.1, C96.1, C97.1, C98.1, FB1.1, U11.7 (DVDD12), U11.10 (AVDD12), U11.13 (DVDD12), U11.16 (AVDD12), U11.34 (AVDD12), U11.37 (DVDD12), U11.43 (DVDD12), U11.46 (AVDD12), U11.49 (DVDD12), U11.52 (AVDD12), U11.53 (AVDD12); also elsewhere on the board
+3V3: C103.1, C104.1, C105.1, C106.1, C107.1, C108.1, C109.1, C110.1, C111.1, C112.1, FB2.1, R30.1, R31.2, R32.1, R33.2, R34.1, R35.1, R36.1, U11.28 (VDD_IO), U11.30 (OVRCURR), U11.56 (AVDD33), U11.61 (AVDD33), U11.66 (AVDD33); also elsewhere on the board
+5V: R50.1, U11.18 (VBUS_DS); also elsewhere on the board
/04 Hub Controller/DVDD12: C72.1, C73.1, C74.1, C75.1, C76.1, C77.1, C78.1, C79.1, C80.1, C81.1, FB1.2, U11.1 (DVDD12), U11.3 (DVDD12), U11.19 (VDD_EFUSE), U11.27 (DVDD12)
/04 Hub Controller/HUB1_DS1_1_TXN: C56.1, U11.48 (DS1_TXM)
/04 Hub Controller/HUB1_DS1_1_TXP: C55.1, U11.47 (DS1_TXP)
/04 Hub Controller/HUB1_DS2_1_TXN: C71.1, U11.42 (DS2_TXM)
/04 Hub Controller/HUB1_DS2_1_TXP: C70.1, U11.41 (DS2_TXP)
/04 Hub Controller/HUB1_DS3_1_TXN: C83.1, U11.39 (DS3_TXM)
/04 Hub Controller/HUB1_DS3_1_TXP: C82.1, U11.38 (DS3_TXP)
/04 Hub Controller/HUB1_DS4_1_TXN: C85.1, U11.12 (DS4_TXM)
/04 Hub Controller/HUB1_DS4_1_TXP: C84.1, U11.11 (DS4_TXP)
/04 Hub Controller/I2C_CLK: R36.2, U11.32 (I2C_CLK)
/04 Hub Controller/I2C_DATA: R35.2, U11.33 (I2C_DATA)
/04 Hub Controller/RESETN: C113.1, R34.2, U11.31 (RESETN)
/04 Hub Controller/SUSPEND: D14.2 (A), U11.20 (SUSPEND)
GND: C50.2, C51.2, C52.2, C53.2, C54.2, C57.2, C58.2, C59.2, C60.2, C61.2, C62.2, C63.2, C64.2, C65.2, C66.2, C67.2, C68.2, C69.2, C72.2, C73.2, C74.2, C75.2, C76.2, C77.2, C78.2, C79.2, C80.2, C81.2, C86.2, C87.2, C88.2, C89.2, C90.2, C91.2, C92.2, C93.2, C94.2, C95.2, C96.2, C97.2, C98.2, C99.2, C100.2, C101.2, C102.2, C103.2, C104.2, C105.2, C106.2, C107.2, C108.2, C109.2, C110.2, C111.2, C112.2, C113.2, R28.1, R29.2, R37.2, R51.2, U11.40 (GND), U11.69 (GND), Y1.2, Y1.4; also elsewhere on the board
HUB1_DS1_DN: U11.59 (DS1_DM); also elsewhere on the board
HUB1_DS1_DP: U11.60 (DS1_DP); also elsewhere on the board
HUB1_DS1_RXN: U11.51 (DS1_RXP); also elsewhere on the board
HUB1_DS1_RXP: U11.50 (DS1_RXM); also elsewhere on the board
HUB1_DS1_TXN: C56.2; also elsewhere on the board
HUB1_DS1_TXP: C55.2; also elsewhere on the board
HUB1_DS2_DN: U11.63 (DS2_DM); also elsewhere on the board
HUB1_DS2_DP: U11.62 (DS2_DP); also elsewhere on the board
HUB1_DS2_RXN: U11.45 (DS2_RXP); also elsewhere on the board
HUB1_DS2_RXP: U11.44 (DS2_RXM); also elsewhere on the board
HUB1_DS2_TXN: C71.2; also elsewhere on the board
HUB1_DS2_TXP: C70.2; also elsewhere on the board
HUB1_DS3_DN: U11.64 (DS3_DM); also elsewhere on the board
HUB1_DS3_DP: U11.65 (DS3_DP); also elsewhere on the board
HUB1_DS3_RXN: U11.36 (DS3_RXM); also elsewhere on the board
HUB1_DS3_RXP: U11.35 (DS3_RXP); also elsewhere on the board
HUB1_DS3_TXN: C83.2; also elsewhere on the board
HUB1_DS3_TXP: C82.2; also elsewhere on the board
HUB1_DS4_DN: U11.68 (DS4_DM); also elsewhere on the board
HUB1_DS4_DP: U11.67 (DS4_DP); also elsewhere on the board
HUB1_DS4_RXN: U11.15 (DS4_RXP); also elsewhere on the board
HUB1_DS4_RXP: U11.14 (DS4_RXM); also elsewhere on the board
HUB1_DS4_TXN: C85.2; also elsewhere on the board
HUB1_DS4_TXP: C84.2; also elsewhere on the board
HUB1_PWR_EN_DS: U11.29 (PWR_EN); also elsewhere on the board
unnamed: C99.1, C100.1, C101.1, C102.1, FB2.2, U11.4 (AVDD33)
unnamed: D14.1 (K), R37.1
unnamed: R32.2, U11.23 (MODE_SEL[0])
unnamed: R30.2, U11.24 (MODE_SEL[1])
unnamed: R33.1, U11.21 (RESERVED1)
unnamed: R31.1, U11.22 (RESERVED2)
unnamed: R28.2, U11.26 (RREF_SS)
unnamed: R29.1, U11.2 (RREF_USB2)
unnamed: R50.2, R51.1, U11.17 (VBUS_US)
unnamed: C51.1, U11.55 (XTL_IN), Y1.3
unnamed: C50.1, U11.54 (XTL_OUT), Y1.1
USB_UFP_DN: U11.58 (US_DM); also elsewhere on the board
USB_UFP_DP: U11.57 (US_DP); also elsewhere on the board
USB_UFP_RXN: U11.8 (US_RXM); also elsewhere on the board
USB_UFP_RXP: U11.9 (US_RXP); also elsewhere on the board
USB_UFP_TXN: U11.5 (US_TXM); also elsewhere on the board
USB_UFP_TXP: U11.6 (US_TXP); also elsewhere on the board

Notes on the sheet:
RC Delay for RESETN
These precision resistors should be close to the IC and have a short ground path.
Decoupling taken from HX3 Hardware Design Guidelines
SUSPEND LED
USB Hub Controller
Hub Controller
When we need it...
This MODE_SEL is for configuration using an external I2C master
~220ms reset timing, perhaps a little excessive
I2C
The RESETN pin must be held LOW until both 3.3V and 1.2V supplies are stable.
"The VBUS_US pin should be connected to the VBUS from the US port. This signal is used to detect the US port connection to a Host or a hub." "It is recommended to connect a pair of resistors to the VBUS_US pin to discharge VBUS faster in case of a disconnection event" HX3 Hardware Design Guidelines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
Requires a crystal of 26MHz +- 150ppm, <200uW drive level Parallel resonant, fundamental mode Selected: TXM26M0004322CBCDO00T 100uW 9pF Approximating C_stray as 4pF; using eqn from page 5 of the HX3 Design guidelines C_1 = C_2 = 2 * (C_L - C_S) = 2 * (9 - 4) = 10pF

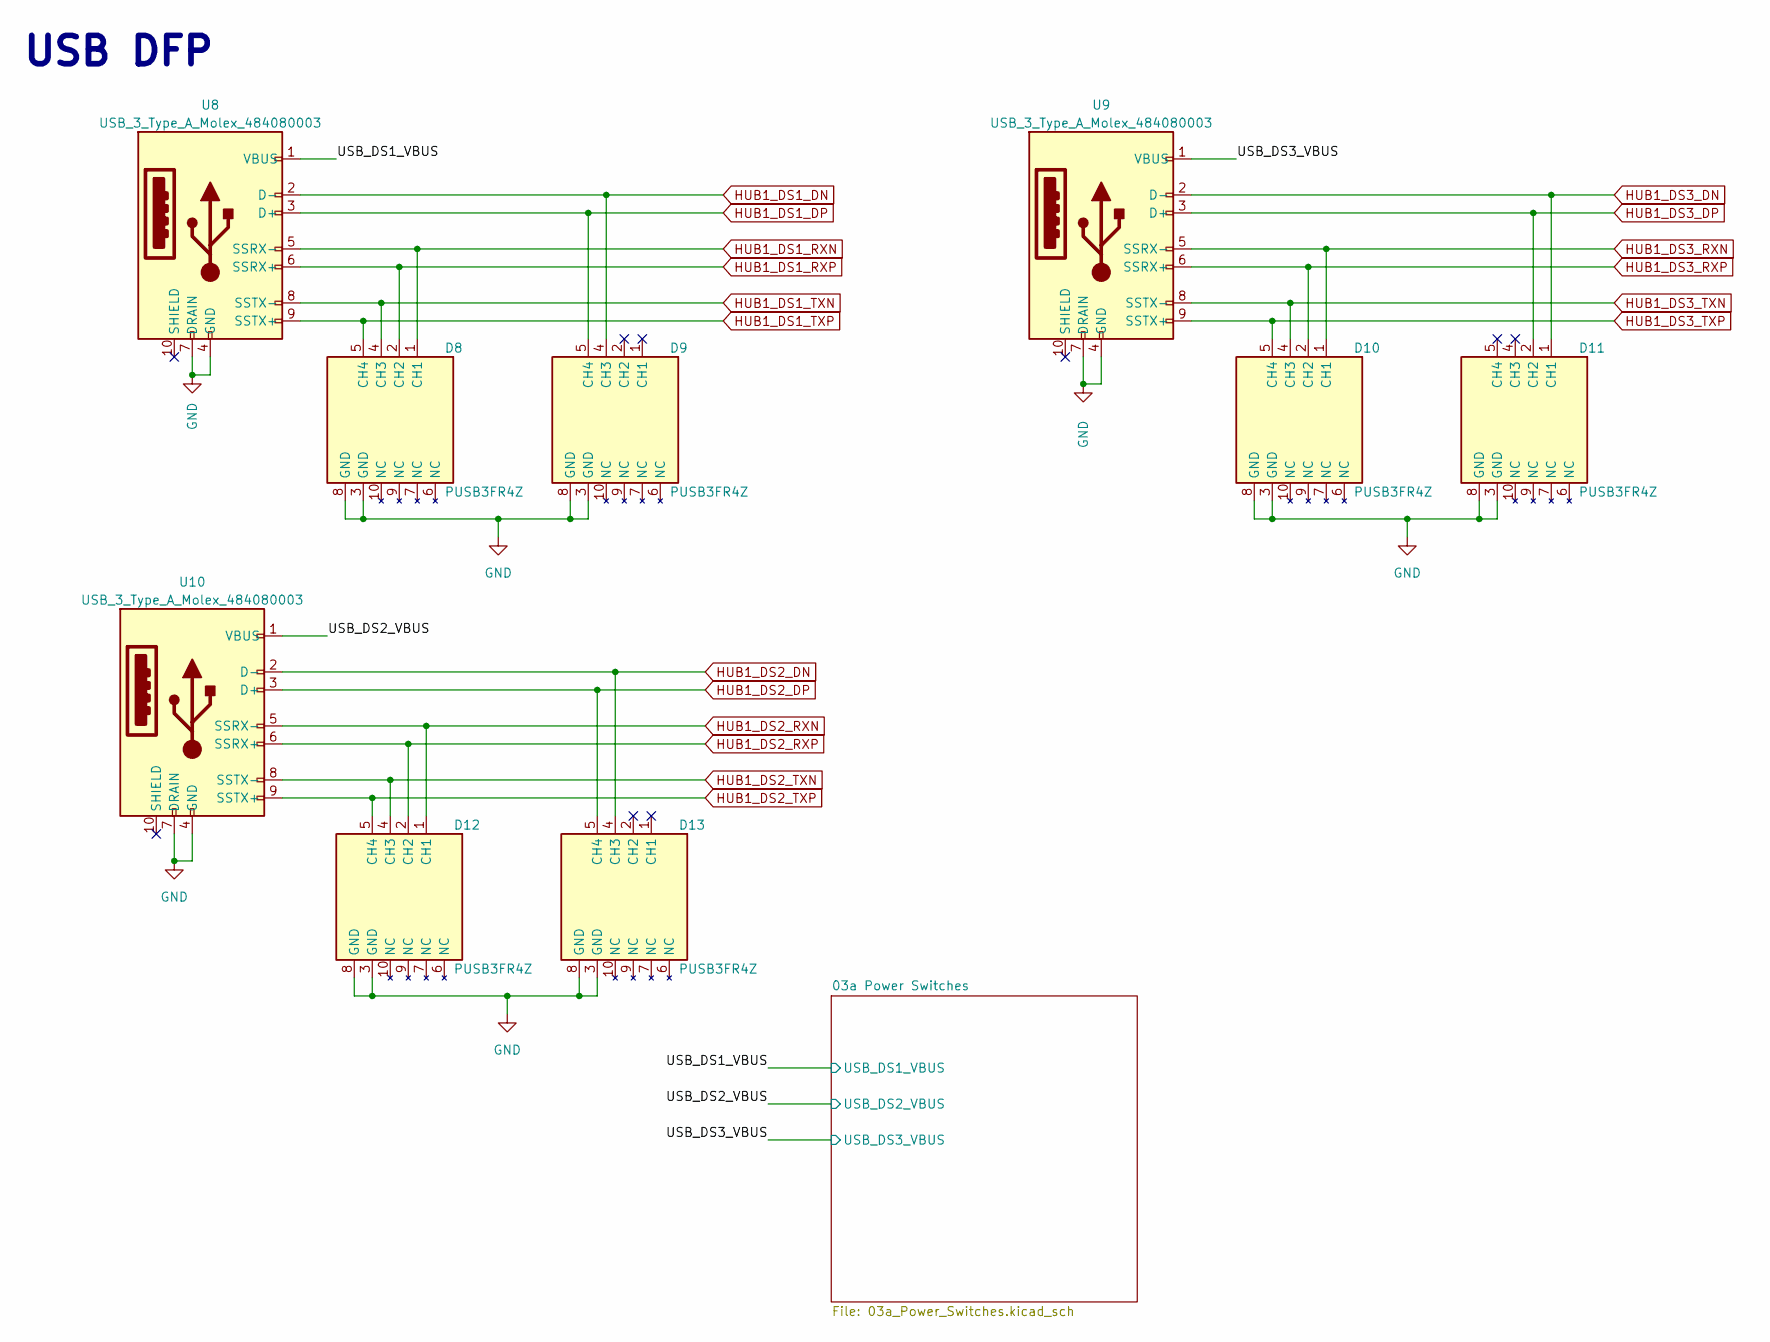
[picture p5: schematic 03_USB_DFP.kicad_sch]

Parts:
D8, D9, D10, D11, D12, D13: PUSB3FR4Z
U8, U9, U10: USB_3_Type_A_Molex_484080003; Molex_484080003

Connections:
/03 USB_DFP/USB_DS1_VBUS: U8.1 (VBUS); also elsewhere on the board
/03 USB_DFP/USB_DS2_VBUS: U10.1 (VBUS); also elsewhere on the board
/03 USB_DFP/USB_DS3_VBUS: U9.1 (VBUS); also elsewhere on the board
GND: D8.3 (GND), D8.8 (GND), D9.3 (GND), D9.8 (GND), D10.3 (GND), D10.8 (GND), D11.3 (GND), D11.8 (GND), D12.3 (GND), D12.8 (GND), D13.3 (GND), D13.8 (GND), U8.4 (GND), U8.7 (DRAIN), U9.4 (GND), U9.7 (DRAIN), U10.4 (GND), U10.7 (DRAIN); also elsewhere on the board
HUB1_DS1_DN: D9.4 (CH3), U8.2 (D-); also elsewhere on the board
HUB1_DS1_DP: D9.5 (CH4), U8.3 (D+); also elsewhere on the board
HUB1_DS1_RXN: D8.1 (CH1), U8.5 (SSRX-); also elsewhere on the board
HUB1_DS1_RXP: D8.2 (CH2), U8.6 (SSRX+); also elsewhere on the board
HUB1_DS1_TXN: D8.4 (CH3), U8.8 (SSTX-); also elsewhere on the board
HUB1_DS1_TXP: D8.5 (CH4), U8.9 (SSTX+); also elsewhere on the board
HUB1_DS2_DN: D13.4 (CH3), U10.2 (D-); also elsewhere on the board
HUB1_DS2_DP: D13.5 (CH4), U10.3 (D+); also elsewhere on the board
HUB1_DS2_RXN: D12.1 (CH1), U10.5 (SSRX-); also elsewhere on the board
HUB1_DS2_RXP: D12.2 (CH2), U10.6 (SSRX+); also elsewhere on the board
HUB1_DS2_TXN: D12.4 (CH3), U10.8 (SSTX-); also elsewhere on the board
HUB1_DS2_TXP: D12.5 (CH4), U10.9 (SSTX+); also elsewhere on the board
HUB1_DS3_DN: D11.1 (CH1), U9.2 (D-); also elsewhere on the board
HUB1_DS3_DP: D11.2 (CH2), U9.3 (D+); also elsewhere on the board
HUB1_DS3_RXN: D10.1 (CH1), U9.5 (SSRX-); also elsewhere on the board
HUB1_DS3_RXP: D10.2 (CH2), U9.6 (SSRX+); also elsewhere on the board
HUB1_DS3_TXN: D10.4 (CH3), U9.8 (SSTX-); also elsewhere on the board
HUB1_DS3_TXP: D10.5 (CH4), U9.9 (SSTX+); also elsewhere on the board

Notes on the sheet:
USB DFP

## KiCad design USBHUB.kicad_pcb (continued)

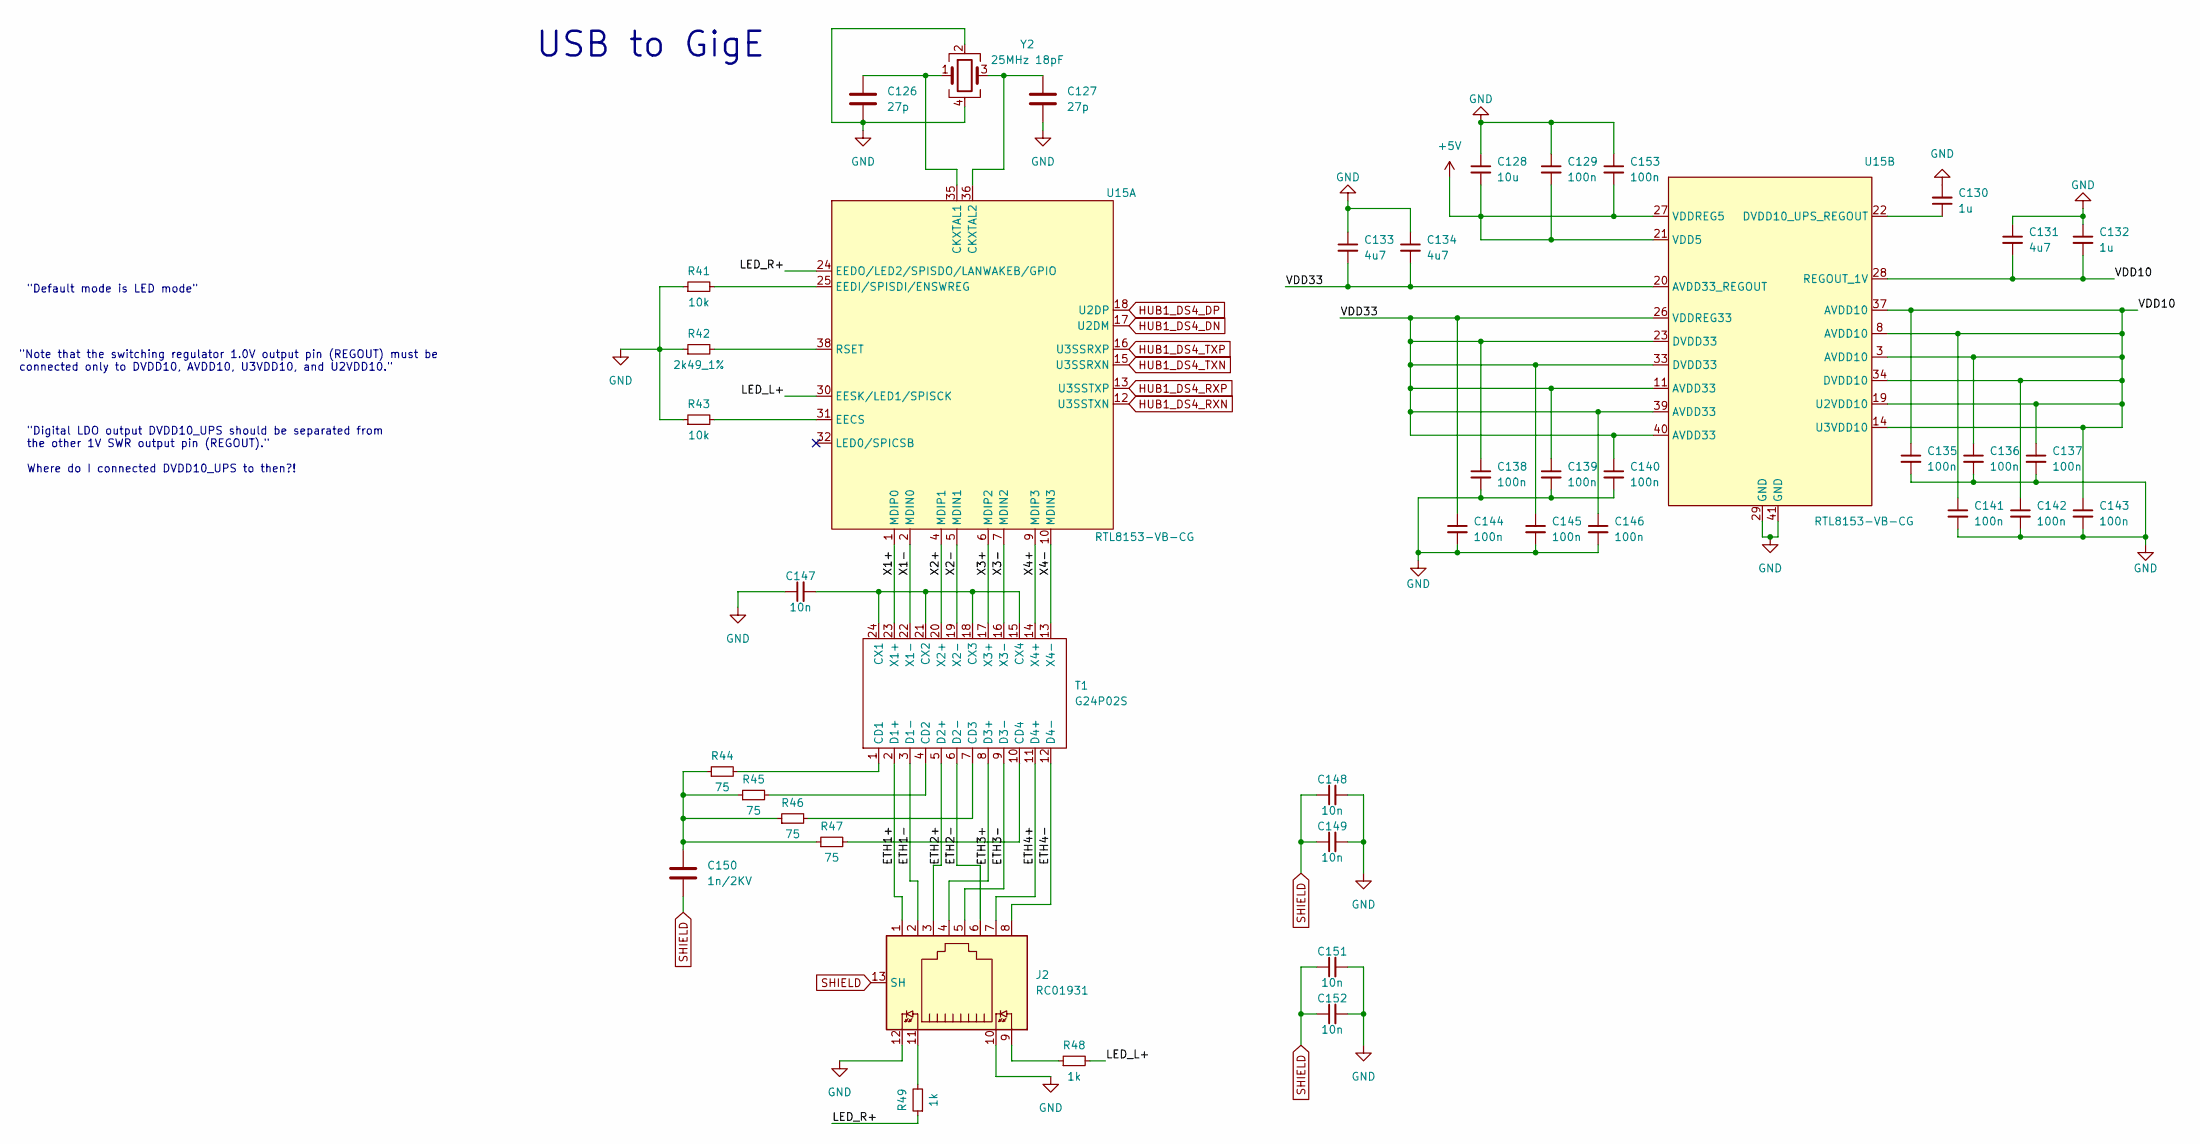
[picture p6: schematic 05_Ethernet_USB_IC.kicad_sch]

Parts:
C126, C127: 27p; C_0402_1005Metric
C128: 10u; C_0603_1608Metric
C129, C135, C136, C137, C138, C139, C140, C141, C142, C143, C144, C145, C146, C153: 100n; C_0402_1005Metric
C130, C132: 1u; C_0603_1608Metric
C131, C133, C134: 4u7; C_0603_1608Metric
C147, C148, C149, C151, C152: 10n; C_0402_1005Metric
C150: 1n/2KV; C_1206_3216Metric
J2: RC01931
R41, R43: 10k; R_0402_1005Metric
R42: 2k49_1%; R_0603_1608Metric
R44, R45, R46, R47: 75; R_0603_1608Metric
R48, R49: 1k; R_0603_1608Metric
T1: G24P02S
U15: RTL8153-VB-CG; RTL8153B-VB-CG
Y2: 25MHz 18pF; Crystal_SMD_2016-4Pin_2.0x1.6mm

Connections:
+5V: C128.2, C129.2, C153.2, U15.21 (VDD5), U15.27 (VDDREG5); also elsewhere on the board
/05 Ethernet USB IC/ETH1+: J2.1, T1.2 (D1+)
/05 Ethernet USB IC/ETH1-: J2.2, T1.3 (D1-)
/05 Ethernet USB IC/ETH2+: J2.3, T1.5 (D2+)
/05 Ethernet USB IC/ETH2-: J2.6, T1.6 (D2-)
/05 Ethernet USB IC/ETH3+: J2.4, T1.8 (D3+)
/05 Ethernet USB IC/ETH3-: J2.5, T1.9 (D3-)
/05 Ethernet USB IC/ETH4+: J2.7, T1.11 (D4+)
/05 Ethernet USB IC/ETH4-: J2.8, T1.12 (D4-)
/05 Ethernet USB IC/LED_L+: R48.2, U15.30 (EESK/LED1/SPISCK)
/05 Ethernet USB IC/LED_R+: R49.1, U15.24 (EEDO/LED2/SPISDO/LANWAKEB/GPIO)
/05 Ethernet USB IC/VDD10: C131.2, C132.2, C135.1, C136.1, C137.1, C141.1, C142.1, C143.1, U15.3 (AVDD10), U15.8 (AVDD10), U15.14 (U3VDD10), U15.19 (U2VDD10), U15.28 (REGOUT_1V), U15.34 (DVDD10), U15.37 (AVDD10)
/05 Ethernet USB IC/VDD33: C133.2, C134.2, C138.1, C139.1, C140.1, C144.1, C145.1, C146.1, U15.11 (AVDD33), U15.20 (AVDD33_REGOUT), U15.23 (DVDD33), U15.26 (VDDREG33), U15.33 (DVDD33), U15.39 (AVDD33), U15.40 (AVDD33)
/05 Ethernet USB IC/X1+: T1.23 (X1+), U15.1 (MDIP0)
/05 Ethernet USB IC/X1-: T1.22 (X1-), U15.2 (MDIN0)
/05 Ethernet USB IC/X2+: T1.20 (X2+), U15.4 (MDIP1)
/05 Ethernet USB IC/X2-: T1.19 (X2-), U15.5 (MDIN1)
/05 Ethernet USB IC/X3+: T1.17 (X3+), U15.6 (MDIP2)
/05 Ethernet USB IC/X3-: T1.16 (X3-), U15.7 (MDIN2)
/05 Ethernet USB IC/X4+: T1.14 (X4+), U15.9 (MDIP3)
/05 Ethernet USB IC/X4-: T1.13 (X4-), U15.10 (MDIN3)
GND: C126.2, C127.2, C128.1, C129.1, C130.2, C131.1, C132.1, C133.1, C134.1, C135.2, C136.2, C137.2, C138.2, C139.2, C140.2, C141.2, C142.2, C143.2, C144.2, C145.2, C146.2, C147.1, C148.2, C149.2, C151.2, C152.2, C153.1, J2.10, J2.12, R41.1, R42.1, R43.1, U15.29 (GND), U15.41 (GND), Y2.2, Y2.4; also elsewhere on the board
HUB1_DS4_DN: U15.17 (U2DM); also elsewhere on the board
HUB1_DS4_DP: U15.18 (U2DP); also elsewhere on the board
HUB1_DS4_RXN: U15.12 (U3SSTXN); also elsewhere on the board
HUB1_DS4_RXP: U15.13 (U3SSTXP); also elsewhere on the board
HUB1_DS4_TXN: U15.15 (U3SSRXN); also elsewhere on the board
HUB1_DS4_TXP: U15.16 (U3SSRXP); also elsewhere on the board
unnamed: C150.1, R44.1, R45.1, R46.1, R47.1
unnamed: J2.9, R48.1
unnamed: J2.11, R49.2
unnamed: R44.2, T1.1 (CD1)
unnamed: R45.2, T1.4 (CD2)
unnamed: R46.2, T1.7 (CD3)
unnamed: R47.2, T1.10 (CD4)
unnamed: C147.2, T1.15 (CX4), T1.18 (CX3), T1.21 (CX2), T1.24 (CX1)
unnamed: C126.1, U15.35 (CKXTAL1), Y2.1
unnamed: C127.1, U15.36 (CKXTAL2), Y2.3
unnamed: R43.2, U15.31 (EECS)
unnamed: R41.2, U15.25 (EEDI/SPISDI/ENSWREG)
unnamed: R42.2, U15.38 (RSET)
unnamed: C130.1, U15.22 (DVDD10_UPS_REGOUT)
SHIELD: C148.1, C149.1, C150.2, C151.1, C152.1, J2.13 (SH)

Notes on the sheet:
"Note that the switching regulator 1.0V output pin (REGOUT) must be connected only to DVDD10, AVDD10, U3VDD10, and U2VDD10."
USB to GigE
"Digital LDO output DVDD10_UPS should be separated from the other 1V SWR output pin (REGOUT)." Where do I connected DVDD10_UPS to then?!
"Default mode is LED mode"

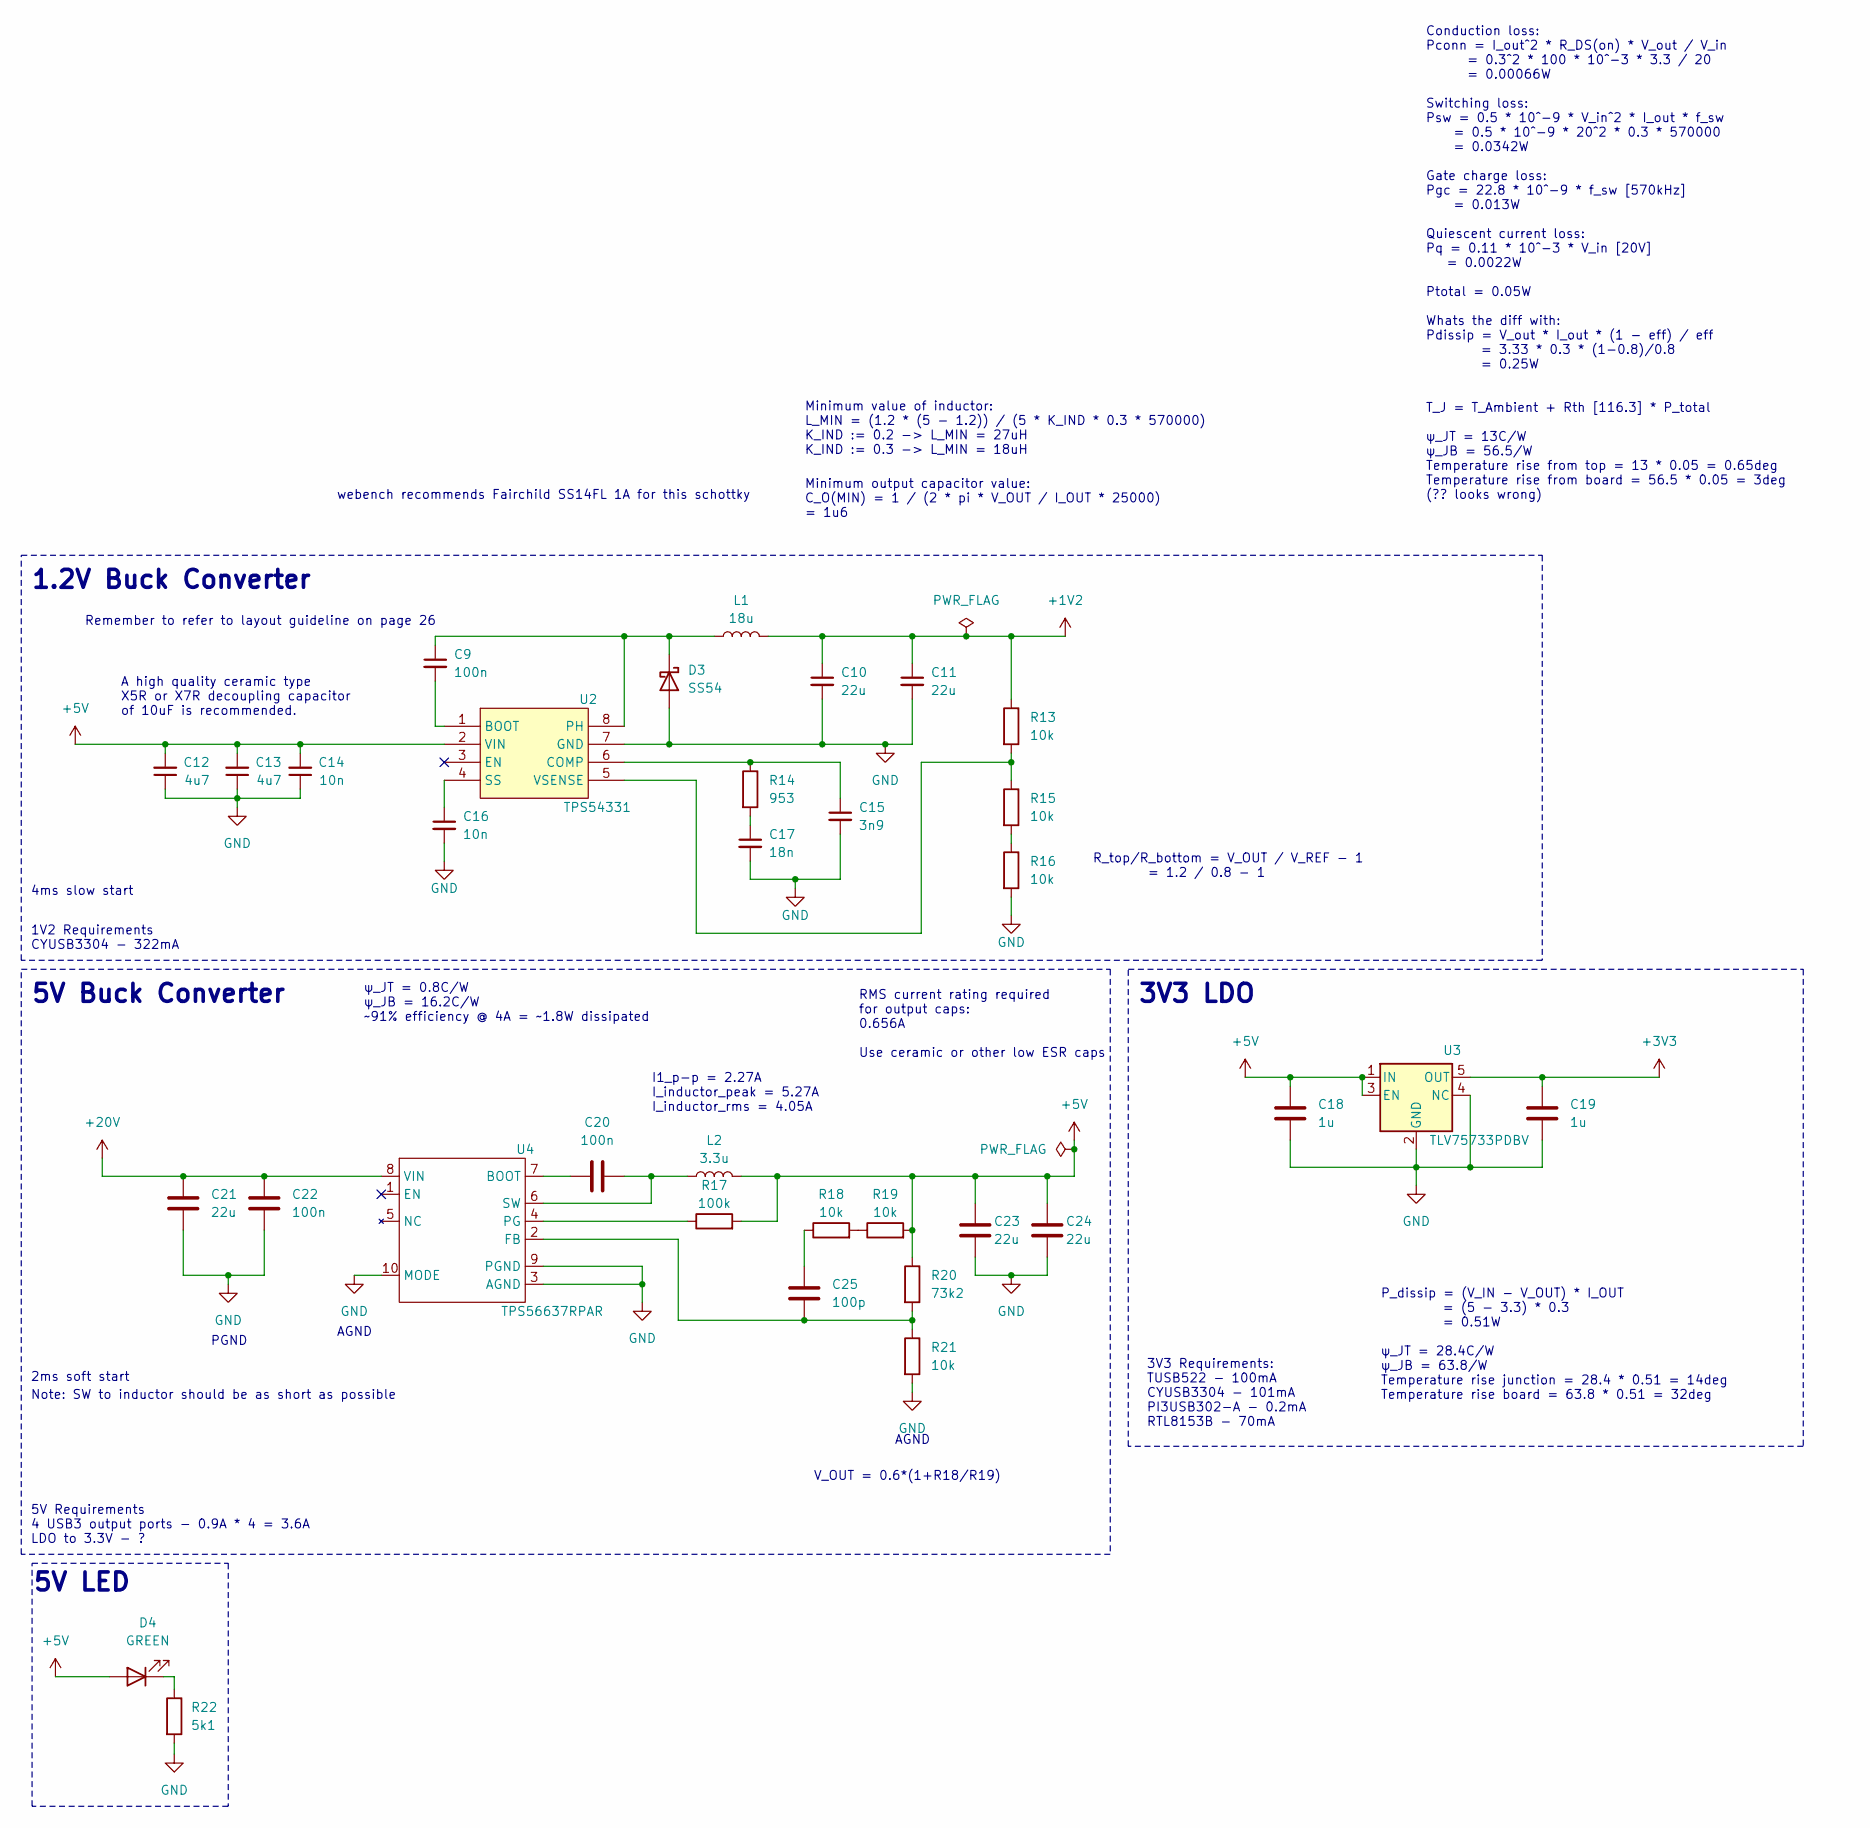
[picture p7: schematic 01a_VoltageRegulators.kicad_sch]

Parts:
C9, C20, C22: 100n; C_0603_1608Metric
C10, C11: 22u; C_0603_1608Metric
C12, C13: 4u7; C_0603_1608Metric
C14, C16: 10n; C_0603_1608Metric
C15: 3n9; C_0603_1608Metric
C17: 18n; C_0603_1608Metric
C18, C19: 1u; C_0603_1608Metric
C21, C23, C24: 22u; C_0805_2012Metric
C25: 100p; C_0603_1608Metric
D3: SS54; D_SMA
D4: GREEN; LED_0603_1608Metric
L1: 18u; FNR6045Sx
L2: 3.3u; FXL0630x
R13, R15, R16, R18, R19, R21: 10k; R_0402_1005Metric
R14: 953; R_0603_1608Metric
R17: 100k; R_0603_1608Metric
R20: 73k2; R_0402_1005Metric
R22: 5k1; R_0603_1608Metric
U2: TPS54331; TPS54331DR
U3: TLV75733PDBV; SOT-23-5
U4: TPS56637RPAR

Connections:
+1V2: C10.1, C11.1, L1.2, R13.1; also elsewhere on the board
+3V3: C19.1, U3.5 (OUT); also elsewhere on the board
+5V: C12.2, C13.2, C14.2, C18.1, C23.1, C24.1, D4.2 (A), L2.2, R17.2, R19.2, R20.1, U2.2 (VIN), U3.1 (IN), U3.3 (EN); also elsewhere on the board
+20V: C21.1, C22.1, U4.8 (VIN); also elsewhere on the board
GND: C10.2, C11.2, C12.1, C13.1, C14.1, C15.2, C16.2, C17.2, C18.2, C19.2, C21.2, C22.2, C23.2, C24.2, D3.2 (A), R16.2, R21.2, R22.2, U2.7 (GND), U3.2 (GND), U3.4 (NC), U4.3 (AGND), U4.9 (PGND), U4.10 (MODE); also elsewhere on the board
unnamed: C17.1, R14.2
unnamed: C25.1, R18.1
unnamed: C9.1, D3.1 (K), L1.1, U2.8 (PH)
unnamed: D4.1 (K), R22.1
unnamed: R15.2, R16.1
unnamed: R18.2, R19.1
unnamed: C9.2, U2.1 (BOOT)
unnamed: C15.1, R14.1, U2.6 (COMP)
unnamed: C16.1, U2.4 (SS)
unnamed: R13.2, R15.1, U2.5 (VSENSE)
unnamed: C20.1, U4.7 (BOOT)
unnamed: C25.2, R20.2, R21.1, U4.2 (FB)
unnamed: R17.1, U4.4 (PG)
unnamed: C20.2, L2.1, U4.6 (SW)

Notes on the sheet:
3V3 LDO
R_top/R_bottom = V_OUT / V_REF - 1 = 1.2 / 0.8 - 1
V_OUT = 0.6*(1+R18/R19)
5V Requirements 4 USB3 output ports - 0.9A * 4 = 3.6A LDO to 3.3V - ?
AGND
5V LED
2ms soft start
4ms slow start
Note: SW to inductor should be as short as possible
3V3 Requirements: TUSB522 - 100mA CYUSB3304 - 101mA PI3USB302−A - 0.2mA RTL8153B - 70mA
RMS current rating required for output caps: 0.656A Use ceramic or other low ESR caps
Remember to refer to layout guideline on page 26
I1_p-p = 2.27A I_inductor_peak = 5.27A I_inductor_rms = 4.05A
1V2 Requirements CYUSB3304 - 322mA
A high quality ceramic type X5R or X7R decoupling capacitor of 10uF is recommended.
P_dissip = (V_IN - V_OUT) * I_OUT = (5 - 3.3) * 0.3 = 0.51W ψ_JT = 28.4C/W ψ_JB = 63.8/W Temperature rise junction = 28.4 * 0.51 = 14deg Temperature rise board = 63.8 * 0.51 = 32deg
5V Buck Converter
Minimum output capacitor value: C_O(MIN) = 1 / (2 * pi * V_OUT / I_OUT * 25000) = 1u6
webench recommends Fairchild SS14FL 1A for this schottky
Minimum value of inductor: L_MIN = (1.2 * (5 - 1.2)) / (5 * K_IND * 0.3 * 570000) K_IND := 0.2 -> L_MIN = 27uH K_IND := 0.3 -> L_MIN = 18uH
1.2V Buck Converter
Conduction loss: Pconn = I_out^2 * R_DS(on) * V_out / V_in = 0.3^2 * 100 * 10^-3 * 3.3 / 20 = 0.00066W Switching loss: Psw = 0.5 * 10^-9 * V_in^2 * I_out * f_sw = 0.5 * 10^-9 * 20^2 * 0.3 * 570000 = 0.0342W Gate charge loss: Pgc = 22.8 * 10^-9 * f_sw [570kHz] = 0.013W Quiescent current loss: Pq = 0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
ψ_JT = 0.8C/W ψ_JB = 16.2C/W ~91% efficiency @ 4A = ~1.8W dissipated
PGND

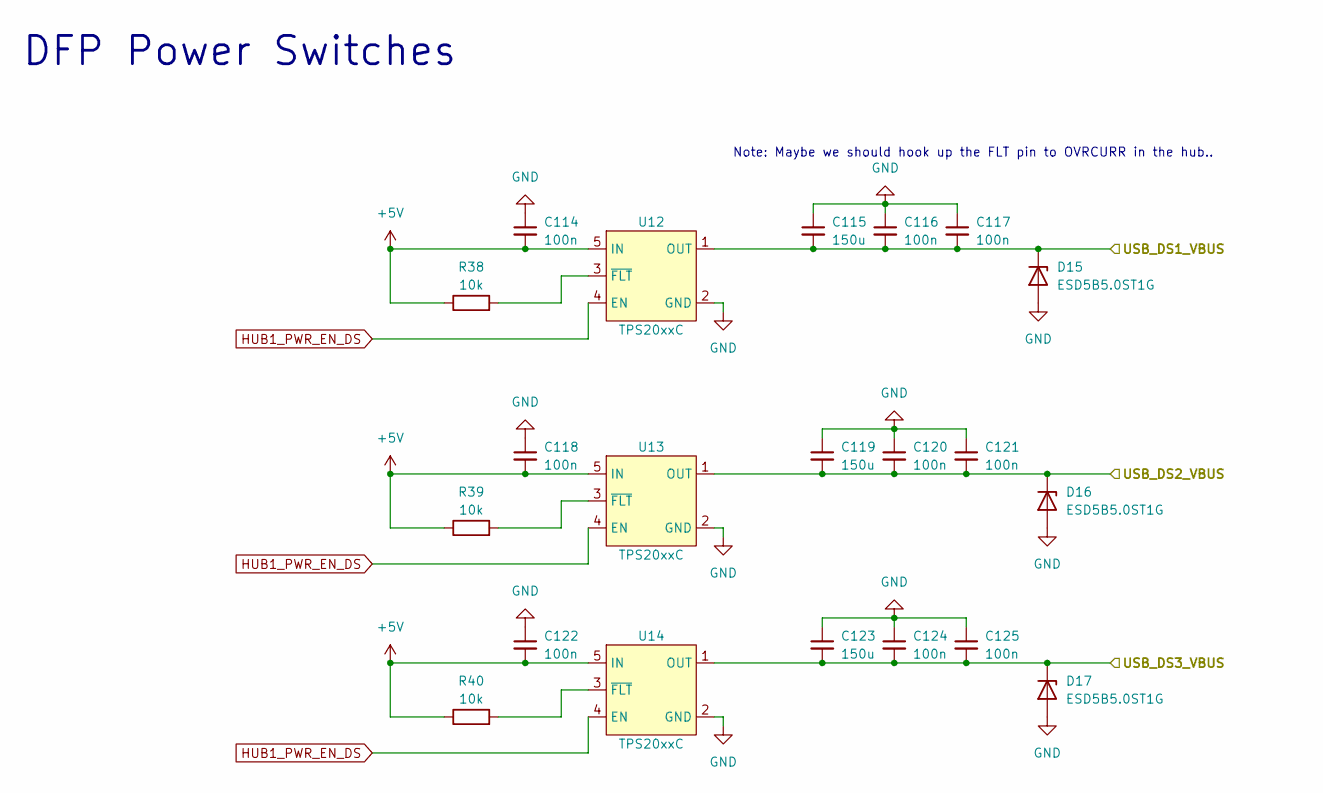
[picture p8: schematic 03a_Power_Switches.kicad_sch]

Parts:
C114, C116, C117, C118, C120, C121, C122, C124, C125: 100n; C_0603_1608Metric
C115, C119, C123: 150u; C_Elec_6.3x7.7
D15, D16, D17: ESD5B5.0ST1G; D_SOD-523
R38, R39, R40: 10k; R_0402_1005Metric
U12, U13, U14: TPS20xxC; SOT-23-5

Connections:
+5V: C114.2, C118.2, C122.2, R38.1, R39.1, R40.1, U12.5 (IN), U13.5 (IN), U14.5 (IN); also elsewhere on the board
/03 USB_DFP/USB_DS1_VBUS: C115.2, C116.2, C117.2, D15.1 (K), U12.1 (OUT); also elsewhere on the board
/03 USB_DFP/USB_DS2_VBUS: C119.2, C120.2, C121.2, D16.1 (K), U13.1 (OUT); also elsewhere on the board
/03 USB_DFP/USB_DS3_VBUS: C123.2, C124.2, C125.2, D17.1 (K), U14.1 (OUT); also elsewhere on the board
GND: C114.1, C115.1, C116.1, C117.1, C118.1, C119.1, C120.1, C121.1, C122.1, C123.1, C124.1, C125.1, D15.2 (A), D16.2 (A), D17.2 (A), U12.2 (GND), U13.2 (GND), U14.2 (GND); also elsewhere on the board
HUB1_PWR_EN_DS: U12.4 (EN), U13.4 (EN), U14.4 (EN); also elsewhere on the board
unnamed: R38.2, U12.3 (~FLT)
unnamed: R39.2, U13.3 (~FLT)
unnamed: R40.2, U14.3 (~FLT)

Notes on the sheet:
DFP Power Switches
Note: Maybe we should hook up the FLT pin to OVRCURR in the hub..

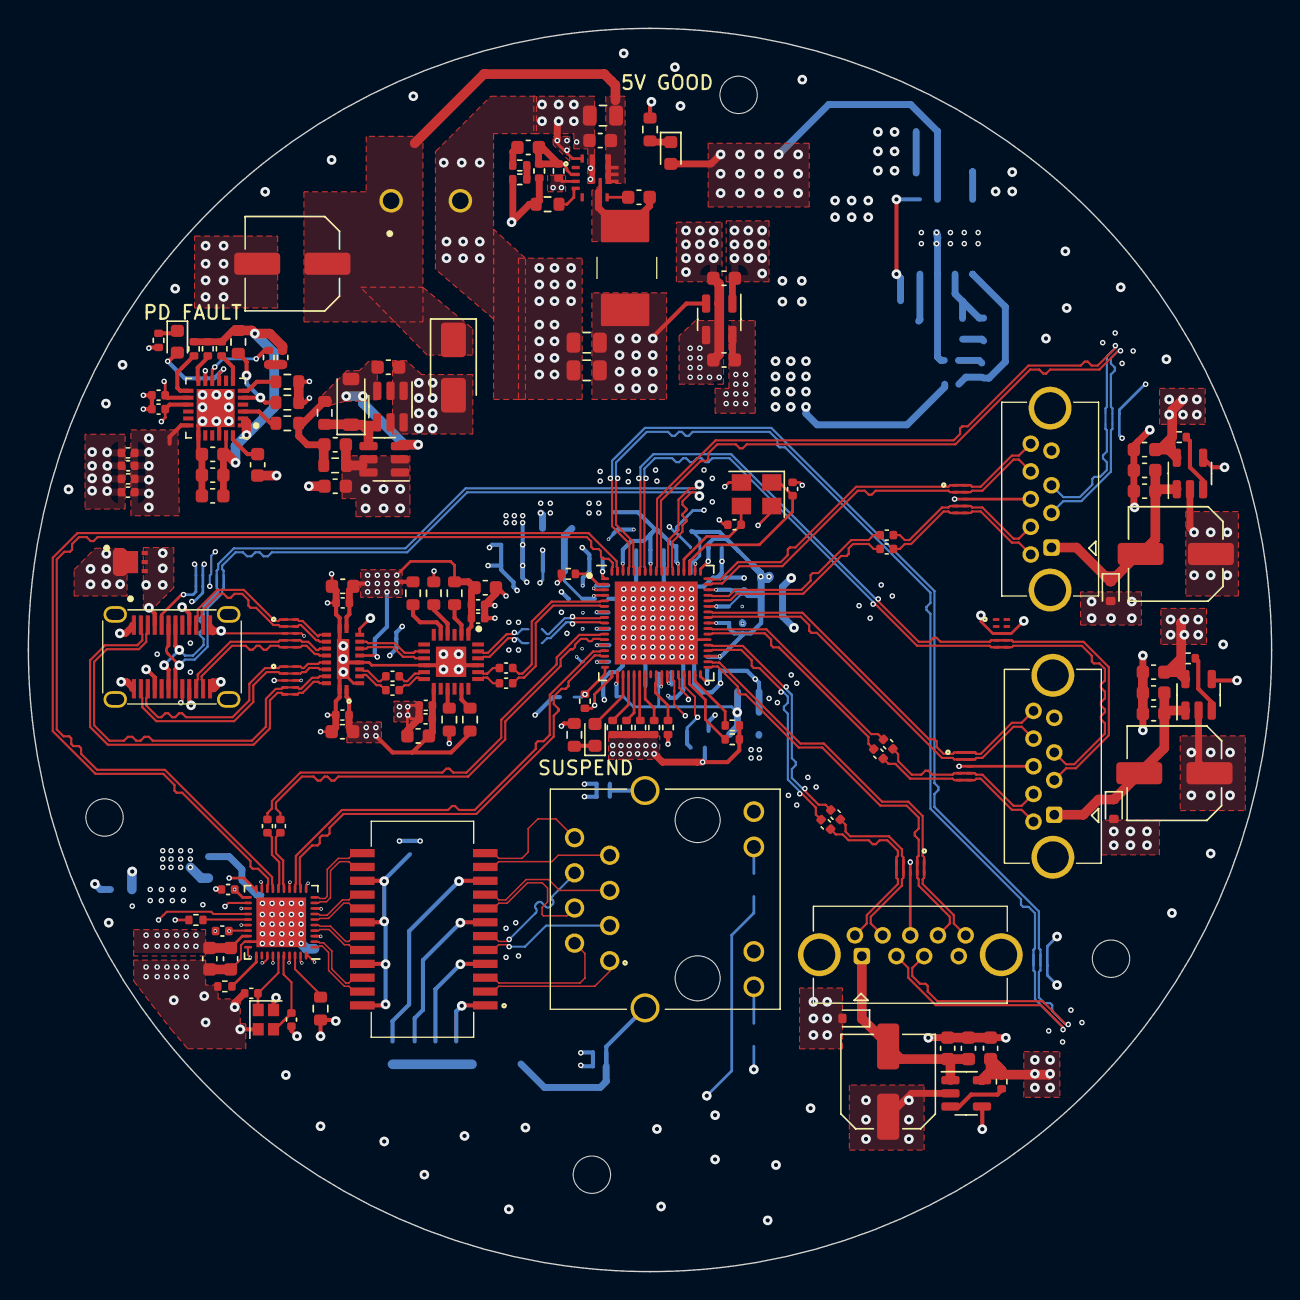
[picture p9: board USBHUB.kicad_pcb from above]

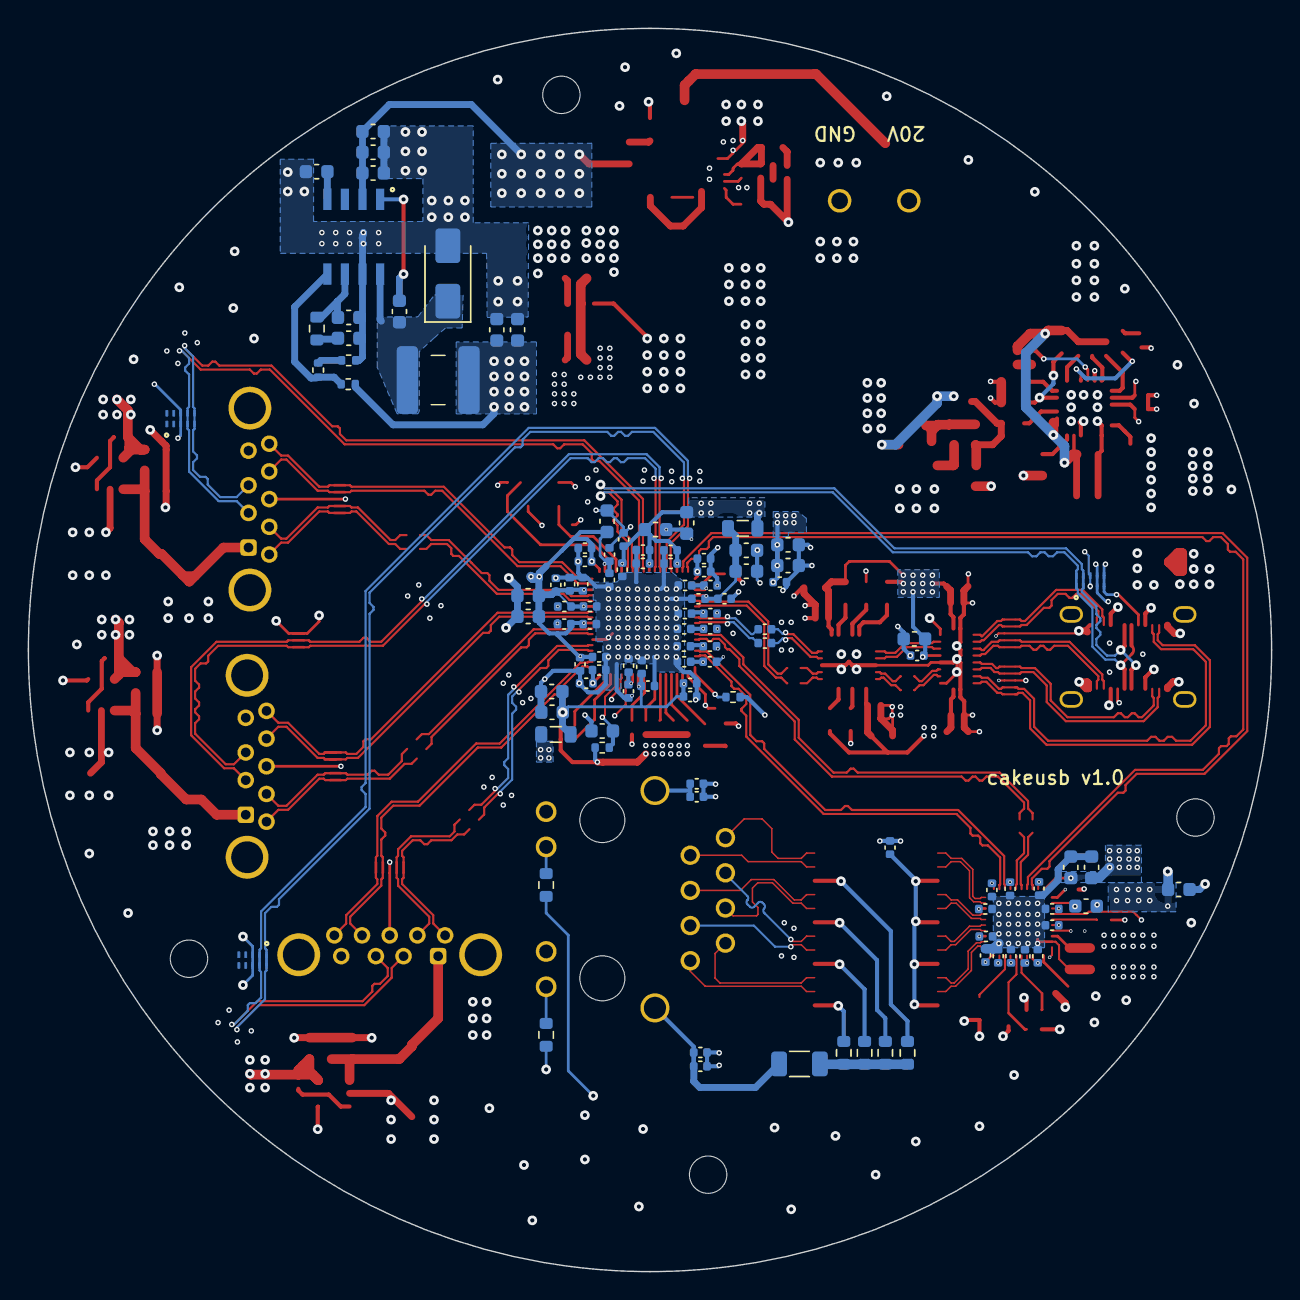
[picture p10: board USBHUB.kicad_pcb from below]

Board: 6 copper layers, 89.8 x 89.8 mm, 253 parts (109 on the bottom side), 156 nets.

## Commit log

2024-01-14 update readme, WIP on PD
    [PowerDelivery.kicad_sch]
2024-01-16 more WIP on power delivery
    [PowerDelivery.kicad_sch]
2024-01-19 finish PD controller schematic
    [HubController.kicad_sch, PowerDelivery.kicad_sch, USBHUB.kicad_sch]
2024-01-19 update grid spacing
    [PowerDelivery.kicad_sch]
2024-01-19 fix warnings
    [HubController.kicad_sch, PowerDelivery.kicad_sch]
2024-01-20 paste kicad symbols and libs directly in here
    [PowerDelivery.kicad_sch]
2024-01-21 start layout of usb PD
    [HubController.kicad_sch, PowerDelivery.kicad_sch, USBHUB.kicad_pcb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]
2024-01-21 Finish PCB design
    [USBHUB.kicad_pcb, USBHUB.kicad_sch]
2024-01-21 some touchups
    [USBHUB.kicad_pcb, USBHUB.kicad_sch]
2024-01-21 add manufacturing files
    [USBHUB-BOM.csv, USBHUB.kicad_pcb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]
2024-01-23 Add ESD for usb parts research, add TUSB522P and PI3USB302
    [01_Power.kicad_sch, 02_USB_UFP.kicad_sch, 03_USB_DFP.kicad_sch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]
2024-01-24 Add ESD protection for UFP, create buck converter model
    [01_Power.kicad_sch, 01a_BuckConverters.kicad_sch, 02_USB_UFP.kicad_sch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]
2024-01-25 more work on the power section
    [01_Power.kicad_sch, 01a_BuckConverters.kicad_sch, 01a_VoltageRegulators.kicad_sch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]
2024-01-26 add usb hub controller schematic, fix up redriver
    [01_Power.kicad_sch, 01a_VoltageRegulators.kicad_sch, 01b_VoltageRegulators.kicad_sch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]
2024-01-29 WIP hub and DFP
    [01a_VoltageRegulators.kicad_sch, 02_USB_UFP.kicad_sch, 03_USB_DFP.kicad_sch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]
2024-01-31 use simpler buck for 5V
    [01a_VoltageRegulators.kicad_sch]
2024-02-01 finish up schematics and ERC
    [01_Power.kicad_sch, 01a_VoltageRegulators.kicad_sch, 02_USB_UFP.kicad_sch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]
2024-02-01 update kicad syms
2024-02-02 finish setting footprints
    [01_Power.kicad_sch, 01a_VoltageRegulators.kicad_sch, 02_USB_UFP.kicad_sch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]
2024-02-05 symbol fixes, switch ESD protection for USB datalines
    [01_Power.kicad_sch, 01a_VoltageRegulators.kicad_sch, 02_USB_UFP.kicad_sch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]
2024-02-12 fix symbols, route UFP DPs and voltage regs
    [01_Power.kicad_sch, 01a_VoltageRegulators.kicad_sch, 02_USB_UFP.kicad_sch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]
2024-02-17 add RTL8153
    [01a_VoltageRegulators.kicad_sch, 03_USB_DFP.kicad_sch, 03a_Power_Switches.kicad_sch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]
2024-02-19 route power delivery controller
    [01_Power.kicad_sch, 01a_VoltageRegulators.kicad_sch, 02_USB_UFP.kicad_sch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]
2024-02-25 settle on a layout
    [01_Power.kicad_sch, 02_USB_UFP.kicad_sch, 04_HubController.kicad_sch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]
2024-02-26 working on pcb
    [USBHUB.kicad_pcb]
2024-02-28 power layout for ethernet usb nic
    [05_Ethernet_USB_IC.kicad_sch, USBHUB.kicad_pcb]
2024-03-04 add schottky for usb pd
    [01_Power.kicad_sch, 01a_VoltageRegulators.kicad_sch, USBHUB.kicad_pcb]
2024-03-10 finish layout draft
    [01a_VoltageRegulators.kicad_sch, 03_USB_DFP.kicad_sch, 04_HubController.kicad_sch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]
2024-03-10 fixing drcs
    [04_HubController.kicad_sch, USBHUB.kicad_pcb]
2024-03-11 fix gnd plane splits
    [USBHUB.kicad_pcb]
2024-03-13 finish bom list
    [01a_VoltageRegulators.kicad_sch, 04_HubController.kicad_sch, 05_Ethernet_USB_IC.kicad_sch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]
2024-03-13 fix bom
    [02_USB_UFP.kicad_sch, 04_HubController.kicad_sch, USBHUB.kicad_pcb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]
